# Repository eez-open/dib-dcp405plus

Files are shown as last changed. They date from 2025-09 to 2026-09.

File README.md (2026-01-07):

### This is a WORK IN PROGRESS!

---

### Ownership and License
The contributors are listed in CONTRIB.TXT. 

Licenses | OSHWA UID
--|--
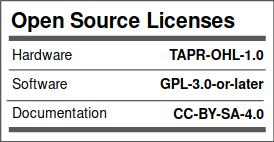
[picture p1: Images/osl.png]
osl
 | OSHW-HR000120 (https://certification.oshwa.org/hr000120.html)

### Overview

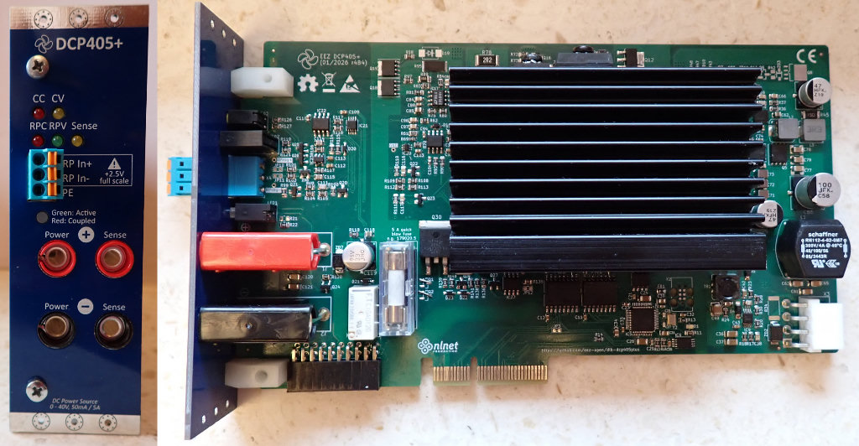
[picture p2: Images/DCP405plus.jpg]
3D model


The EEZ DIB DCP405+ Power module is an improved version of the [DCP405](https://github.com/eez-open/modular-psu/tree/master/dcp405) module that now includes an on-board 32-bit MCU, a more accurate and faster A/D converter for simultaneous voltage and current measurement (and thus more accurate power measurement).
This version features remote current programming in addition to the existing remote voltage programming. Sense inputs are also on 4 mm safety sockets, which now enables usage of widely available (e.g. AliExpress, eBay, etc.) and affordable Kelvin cable sets (Power/Sense) usually used with LCR meters (see below)

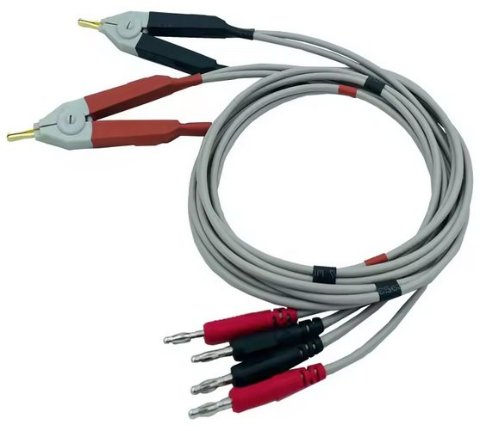
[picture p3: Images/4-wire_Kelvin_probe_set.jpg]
Probe set


### Feature list
- Power input: 48 Vdc (e.g. Mean Well EPP-150-48 or LRS-150F-48)
- Max. output power: 155 W (as limited with Mean Well AC/DC module capacity) 
- Voltage regulation (CV), 0 – 40 V. Voltage set resolution (_U_SET_): 16-bit, read resolution (_U_MON_): 15-bit
- Current regulation (CC) with 2-range (50 mA, 5 A). Current set resolution (_I_SET_): 16-bit, Current read resolution (_I_MON_): 20-bit for each range
- On-board low EMI switching power pre-regulator and bias power supply
- On-board OVP with full range dual crowbar (triac/MOSFET) and 20x5 mm fuse
- Down-programmer
- Output enable (OE) circuit with LED indicator combined with coupling indication
- Ø4 mm sockets (19.05 mm/0.75” pitch) for Power outputs and Sense inputs 
- Pass-thru connector for power output coupling with other power boards for e.g. doubling output voltage (up to 80 V) or current (up to 10 A)
- Remote voltage sense with LED indicator and inverse polarity protection
- Remote voltage and current programming with LED indicator (+2.5 V for full range)
- On-board 32-bit 250 MHz MCU ([STM32H503CBT6](https://www.st.com/en/microcontrollers-microprocessors/stm32h503cb.html))
- Galvanically isolated SPI bus
- I2C EEPROM for storing board specific configuration and calibration parameters
- SPI Temperature sensor
- Dimensions: 180 x 103.5 mm, 4-layer PCB
- **CE certified design**

---

This work is financed by [NLnet](https://nlnet.nl/project/BB3-CM5/) foundation

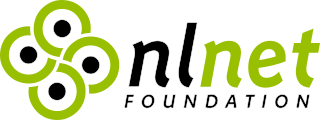
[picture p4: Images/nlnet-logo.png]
nlnet


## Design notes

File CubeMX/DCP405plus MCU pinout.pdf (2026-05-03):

DCP405plus MCU pinout | 03.05.2026
Pin Nb | PINs | FUNCTIONs | LABELs | NOTE
2 | PC13 | GPIO_Output | ACT_LED
4 | PC15-OSC32_OUT(OSC32_OUTGPIO_Input | TYPE_ID
5 | PH0-OSC_IN(PH0) | RCC_OSC_IN
6 | PH1-OSC_OUT(PH1) | RCC_OSC_OUT
10 | PA0 | SPI1_MISO | DIB_MISO
11 | PA1 | SPI1_NSS | DIB_CSA
12 | PA2 | SPI1_SCK | DIB_CLK
13 | PA3 | SPI3_MOSI | MOSI1
14 | PA4 | SPI1_MOSI | DIB_MOSI
15 | PA5 | SPI2_SCK | ADC_SCLK
16 | PA6 | GPIO_EXTI6 | IOEXP_IRQ
17 | PA7 | SPI2_MISO | ADC_MISO
18 | PB0 | GPIO_Output | DIB_IRQ
19 | PB1 | SPI2_MOSI | ADC_MOSI
20 | PB2 | GPIO_Input | ADC_IRQ
21 | PB10 | I2C1_SDA | DIB_SDA
25 | PB12 | GPIO_Output | IOEXP_CS
26 | PB13 | I2C1_SMBA | DIB_ALERT
27 | PB14 | USART1_TX
28 | PB15 | SPI3_MISO | MISO1
29 | PA8 | GPIO_Output | ADC_CS
30 | PA9 | GPIO_Output | DAC_CS
31 | PA10 | GPIO_Output | DIB_FAULT
32 | PA11 | USB_DM
33 | PA12 | USB_DP
34 | PA13(JTMS/SWDIO) | DEBUG_JTMS-SWDIO | JTAG_DIO
37 | PA14(JTCK/SWCLK) | DEBUG_JTCK-SWCLK | JTAG_CLK
38 | PA15(JTDI) | SPI3_SCK | SCLK1
39 | PB3(JTDO/TRACESWO) | DEBUG_JTDO-SWO | JTAG_SWO
40 | PB4(NJTRST) | TIM1_CH2 | AC_FREQ

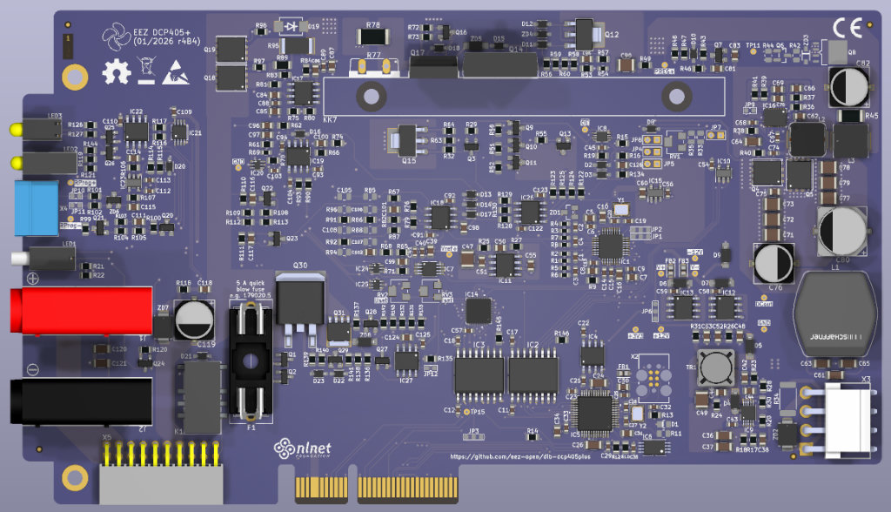
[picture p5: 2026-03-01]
Images/DCP405plus_3D.jpg

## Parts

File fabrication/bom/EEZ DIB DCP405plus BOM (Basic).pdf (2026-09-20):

EEZ DIB DCP405plus BOM (Basic), 20.09.2026

# | Reference | Value | Qty | DigiKey | Mouser | TME | LCSC

1 | C1,C2,C3,C4,C32,C59 | 1n | 6 | 732-7858-1-ND | 81-GRT1885C2A102JA2D C0805C102J5GAC
2 | | 1u | 14 | 587-1283-1-ND | | CL21B105KOFNNNE
3 | | 100n | 36 | 490-4774-1-ND | 80-C0603C104M4R | CL10B104KA8NNNC
4 | C14 | 270n | 1 | 490-16405-1-ND | GCM188R71C274KA37D C710684
5 | C17,C18 | 10p | 2 | 1276-1069-1-ND | 187-CL10C100CB8NNNC VJ0603A100JXACW1BC C318677
6 | C24,C26 | 2u2 | 2 | 490-12332-1-ND | | GRT188R61H225KE13D
7 | C27,C28 | 30p | 2 | 1292-1515-1-ND | 80-C0603C300G5HACTU 0603N300J500CT | C123555
8 | C34,C44,C119,C121,C122 | 4u7 | 5 | 1276-1244-1-ND | 187-CL21A475KAQNNNE CL21A475KAQNNNE | C1779
9 | C40,C120 | 22u | 2 | 1276-1101-1-ND | 187-CL32A226KAJNNNE CL32A226KAJNNNE | C52306
10 | C46,C48,C50,C105,C106 | 10n/200V | 5 | 311-4491-1-ND | 603-C1206KRX7RABB103 VJ1206Y103KXCTW1BC
11 | C47,C60,C103 | 470n/100V | 3 | 587-5014-1-ND | GRM21BR72A474KA73L C97926
12 | C49,C112,C113 | 2u2 | 3 | 1276-3138-1-ND | 187-CL31B225KCHSNNE C3216X7S2A225KAB
13 | C51,C54,C69,C71,C80,C114,C115 | 10n | 7 | 490-7194-1-ND | 710-885012207122 | CC0805KRX7R9103
14 | C53 | 15p | 1 | 399-C0603C150J5GAC7867TR-ND 80-C0603C150J5G | C0603C150J5GAC
15 | C55,C87 | 150p | 2 | 1276-1828-1-ND | 80-C0805C151J5G | CC0805JRNPO9BN151
16 | C56,C57,C58,C75 | 4u7/100V | 4 | 587-5034-1-ND | 810-CGA6M3X7S2A475K -
17 | C61,C67 | EEEFK1H470P | 2 | PCE3815CT-ND | 667-EEE-FK1H470P | EEEFK1H470P | C278400
18 | C62,C63,C64 | 10u | 3 | 1276-6736-1-ND | 187-CL32A106KBJNNNE CL31A106KBHNNNE
19 | C65 | EEEFK1J101P | 1 | PCE3819CT-ND | 667-EEE-FK1J101P | EEEFK1J101P | C128460
20 | C66 | 470p | 1 | 732-7837-1-ND | 710-885012007038 | CC0805JRNPO9BN471
21 | C81 | 6n8 | 1 | 1276-1799-1-ND | 80-C0805C682K5R | CL21B682KBANNNC
22 | C82,C109,C111 | 4n7 | 3 | 732-12255-1-ND | 810-C2012C0G1H472J-1 GRM2165C1H472JA01D
23 | C83 | 100p | 1 | 399-15000-1-ND | 80-C0805C101K5G | CL21C101JBANNNC
24 | C84,C85 | 2n2 | 2 | 399-C0805C222K5RAC7210TR-ND 80-C0805C222K5RACLR CL21B222JBANNNC | C307541
25 | C86,C118 | 330p | 2 | 1276-1189-1-ND | 80-C0805C331J5G | CL21C331JBANNNC
26 | C104 | 33u/50V poly. | 1 | | | - | C2157841
27 | C117 | 33p | 1 | 1276-1105-1-ND | C0805C330K5GACTU | CL21C330JBANNNC
28 | | BAS316 | 15 | 1727-7370-1-ND | 771-BAS316-T/R | BAS316,115 | C109218
29 | D5,D20,D21,D22,D23 | SKL16 | 5 | RB160MM-60CT-ND | 755-RB160MM-60TR | SKL16-DIO | -
30 | F1 | ZH32 | 1 | 732-11370-ND | 710-696101000002 | ZH32
31 | FB1,FB2,FB3 | BLM18AG102SH1D | 3 | 490-7809-1-ND | 81-BLM18AG102SH1D | BLM18AG102SH1D | C337877
32 | IC1 | ADS131A04IPBSR | 1 | 296-44202-1-ND | 595-ADS131A04IPBSR | - | C882747
33 | IC2,IC3 | ISO6762FDWR | 2 | 296-ISO6762FDWRCT-ND | 595-ISO6762FDWR | - | C5216396

C5,C7,C8,C10,C16,C30,C31,C36,C41,C 42,C68,C70,C72,C126

603-
CC805MKX7R7BB105
C6,C9,C11,C12,C13,C15,C19,C20,C21, C22,C23,C25,C29,C33,C35,C37,C38,C3 9,C43,C45,C52,C73,C74,C76,C77,C78, C79,C88,C89,C107,C108,C110,C116,C1 23,C124,C125
81-
GCM188R71C274KA7D

81-
GRT188R61H225KE3D

963-
HMK212C7474MGHTE

565-HHXD630ARA330MHA0GCT-ND

661-
XD630ARA330MHA0G

D1,D2,D3,D4,D6,D7,D8,D9,D10,D11,D1 2,D13,D14,D18,D19

34 | IC4 | ISO6520DR | 1 | 296-ISO6520DRCT-ND | 595-ISO6520DR | - | C32273056
35 | IC5 | STM32H503CBT6 | 1 | 497-STM32H503CBT6-ND | 511-STM32H503CBT6 | STM32H503CBT6 | C17700273
36 | IC6 | M24C32-DFDW6TP | 1 | 497-16067-1-ND | 511-M24C32-DFDW6TP M24C32-DFDW6TP | C2971426
37 | IC7 | DAC8552IDGKR | 1 | 296-46082-1-ND | 595-DAC8552IDGKR | - | C136020
38 | IC8 | 74AUP1G74DC,125 | 1 | 1727-6029-2-ND | 771-AUP1GDC125 | 74AUP1G74DC.125 | C458192
39 | IC9 | TMP126NDCKR | 1 | 296-TMP126NDCKRCT-ND | 595-TMP126NDCKR | TMP126NDCKR | C5219998
40 | IC10 | REF5025AIDR | 1 | 296-39165-1-ND | 595-REF5025AIDR | - | C11341
41 | IC11 | PCAL9722HNMP | 1 | 568-PCAL9722HNMPTR-ND | 771-PCAL9722HNMP | - | C24212503
42 | IC12 | LM5145RGYR | 1 | 296-47661-1-ND | 595-LM5145RGYR | - | C485912
43 | IC13 | LTC2050HVCS8#PBF | 1 | LTC2050HVCS8#PBF-ND | 584-LTC2050HVCS8#PBF - | C679141
44 | IC14,IC15 | TL072D | 2 | 296-1282-1-ND | 595-TL072CDR | TL072CD-ST | C67473
45 | IC16 | SN74LVC1G3157DCKR | 1 | 296-14909-1-ND | SN74LVC1G3157DCKR C38663
46 | IC22 | LM293D | 1 | LM293DR2GOSCT-ND | 863-LM293DR2G | LM293DR | C76509
47 | IC23 | MAX9141ESA | 1 | MAX9141ESA+-ND | 700-MAX9141ESA | - | C3658498
48 | IC24 | TPS54060DGQ | 1 | 296-37148-1-ND | TPS54060ADGQR | - | C12382
49 | IC25 | MC79L05 | 1 | MC79L05ABDGOS-ND | 863-MC79L05ACDR2G | MC79L05ACDG | C232661
50 | IC26 | MC78L05 | 1 | MC78L05ACDR2GOSCT-ND | 863-MC78L05ACDR2G | MC78L05ACDG | C7371
51 | IC27 | TPS7A2033PDBVR | 1 | 296-TPS7A2033PDBVRCT-ND | 595-TPS7A2033PDBVR | TPS7A2033PDBVR | C2862740
52 | J1 | 571-0500 | 1 | - | 164-6219 | 571-0500 | -
53 | J2 | 571-0100 | 1 | - | 164-6218 | 571-0100 | -
54 | KK1,KK2,KK3,KK4,KK7 | M3X8/D7985B | 5 | - | - | M3X8/D7985B
55 | KK5 | SK96/84SA | 1 | 5496-SK9684SA-ND | - | SK96/84SA | -
56 | KK6 | SP400-0.007-00-104 | 1 | BER204-ND | 951-SP400-007-00-104
57 | KK8 | B3/BN2842 | 1 | - | - | B3/BN2842
58 | KK9,KK10 | PCB-MB-01 | 2 | RPC1760-ND | 144-PCB-MB-01 | RI-PCB-MB-01 | C959626
59 | L1 | RN112-4-02-0M7 | 1 | 817-2100-ND | 631-RN112-4-02-0M7 | -
60 | L2 | ETQ-P4M100KFM | 1 | P124167CT-ND | 667-ETQ-P4M100KFM | -
61 | L3 | HPI0630-3R3 | 1 | 445-180834-1-ND | 810-VLS6045AF-3R3N | HPI0630-3R3
62 | LED2 | WP42WUM/EGW | 1 | 754-1718-ND | 604-WP42WUM/EGW | L-42WUM/1EGWT
63 | LED4 | WP934MD/LYLID | 1 | 350-2716-ND | 604-WP934MDLYLID | - | -
64 | Q1 | BSS84 | 1 | BSS84LT1GOSCT-ND | 863-BSS84LT1G | BSS84LT1G | C82079
65 | Q2 | BSC117N08NS5ATMA1 | 1 | BSC117N08NS5ATMA1CT-ND | BSC117N08NS5ATMA1 C3278730
66 | Q3 | BSC039N06NSATMA1 | 1 | BSC039N06NSATMA1CT-ND | | BSC039N06NS | C6471340
67 | Q5,Q8,Q9 | MMBT5401 | 3 | MMBT5401-FDICT-ND | 621-MMBT5401-F | MMBT5401-DIO | C21488
68 | Q7,Q11,Q26 | MMBT5551 | 3 | MMBT5551LT1GOSCT-ND | 637-MMBT5551 | MMBT5551-DIO | C41095
69 | Q10,Q13 | BCP56-16.115 | 2 | BCP5616QTADICT-ND | 621-BCP5616QTA | BCP56-16T1G
70 | Q12 | IRFP250NPBF | 1 | IRFP250NPBF-ND | 942-IRFP250NPBF | IRFP250NPBF
71 | Q14 | BC857C | 1 | 4878-BC857CCT-ND | 637-BC857C | BC857C-DIO | C8666
72 | Q15 | IRFI9Z34GPBF | 1 | IRFI9Z34GPBF-ND | 844-IRFI9Z34GPBF | IRFI9Z34GPBF | C222460
73 | Q16,Q17 | PSMN0R9-25YLC | 2 | 1727-5292-1-ND | 771-PSMN0R925YLC115 PSMN0R9-25YLC.115 | C179450
74 | Q23,Q24,Q25 | 2N7002 | 3 | T2N7002AKLMCT-ND | 757-T2N7002AKLM | 2N7002LT1G
75 | Q27 | FMMT493TA | 1 | FMMT493CT-ND | 522-FMMT493TA | FMMT493TA

595-
SN74LVC1G3157DCK

726-
BSC117N08NS5ATMA
726-
BSC039N06NSATMA1

76 | Q28 | BT139B-600E | 1 | 1740-1053-1-ND | 771-BT139B-600E118 | BT139B-600E.118 | C6533556
77 | Q29 | PSMN013-60YL | 1 | 1727-2589-1-ND | 771-PSMN013-60YLX | PSMN013-60YLX | C503662
78 | R1,R2,R3,R4,R5,R6,R7,R8,R47 | 100R | 9 | 13-RC0603FR-10100RLCT-ND | 603-RT0603FRE07100RL RC0603FR-10100RL | C1512171
79 | R9,R21,R33,R42,R147,R148,R151 | 10R | 7 | YAG1320CT-ND | 603-RC0805FR-0710RP SMD0805-10R-1% | C859127
80 | | 10K | 22 | 311-10.0KCRCT-ND | 603-RC0805FR-0710KL | RC0805FR-1310KL
81 | R11,R13,R19 | 1K8 | 3 | 311-1.80KCRCT-ND | 603-RC0805FR-131K8L | SMD0805-1K8-1% | C137579
82 | R15,R108,R109,R110,R111 | 0R | 5
83 | R17,R23,R39,R136 | 100K | 4 | RMCF0805FT100KCT-ND | | 0805S8F1003T5E
84 | R20,R129 | 330R | 2 | A129743CT-ND | 652-CR0805FX-3300ELF 0805S8F3300T5E
85 | R22,R115 | 1R | 2 | 13-RC0805FR-131RLCT-ND | 603-RC0805FR-131RL | RC0805FR-131RL | C7336808
86 | R30,R50,R63,R90,R91,R144 | 47K | 6 | RHM47KKCT-ND | 603-RC0805FR-0747KL | RC0805FR-0747K
87 | R31,R48,R54 | 470R | 3 | 311-470CRCT-ND | 71-CRCW0805470RFKEB RC0805FR-07470R
88 | R34,R120,R121 | 3K9 | 3 | A126369CT-ND | 279-CRGP0805F3K9 | SMD0805-3K9-1%
89 | R38 | 15R | 1 | A129910CT-ND | 603-RC2010FK-0715RL | 201007J0150T4E
90 | | 1K | 9 | RC0805FR-071KL | 603-RC0805FR-071KL | RC0805FR-071K
91 | R43 | 1K2 | 1 | 311-1.20KCRCT-ND | 603-RC0805FR-071K2L | SMD0805-1K2-1% | C114526
92 | R44,R45,R57,R86 | 220R | 4 | RMCF0805FT220RCT-ND | 603-RC0805FR-13220RL 0805S8F2200T5E
93 | R46,R149 | 51K | 2 | 311-51.0KCRCT-ND | 603-RC0805FR-0751KL | SMD0805-51K-1% | C107233
94 | R51,R59,R64,R65,R66,R67,R143 | 2K2 | 7 | 311-2.20KCRCT-ND | 603-RC0805FR-072K2L | 0805S8F2201T5E
95 | R52 | 16K | 1 | 311-16.0KCRCT-ND | 603-RC0805FR-0716KL | SMD0805-16K-1% | C137588
96 | R53,R124,R125 | 750R | 3 | A126385CT-ND | | 0805S8F7500T5E | C17818
97 | R61 | 6K8 | 1 | 311-6.80KCRCT-ND | 603-RC0805FR-076K8L | SMD0805-6K8-1% | C114550
98 | R62 | 3K | 1 | 311-3.00KCRCT-ND | 603-RC0805FR-073KL | SMD0805-3K-1% | C126350
99 | R68,R122,R123 | 6K2 | 3 | 311-6.20KCRCT-ND | 603-RC0805FR-076K2L | - | C114535
100 | R71 | 2R2/2-3W | 1 | CRM2512-JW-2R2ELFCT-ND | 279-35222R2JT | WF25P2R2JTL
101 | R72,R75 | 7K5 0.1% | 2 | YAG1974CT-ND | 279-CPF0805B7K5E1 | AR05BTCW7501
102 | R73,R74 | 36K 0.1% | 2 | YAG4886CT-ND | 603-RT0805BRD0736K5L - | C865431
103 | R76,R77 | 750R 0.1% | 2 | YAG4940CT-ND | 603-RT0805BRD07750RL ERA6AEB751V | C728656
104 | R79,R80 | 100K 0.1% | 2 | YAG4808CT-ND | 603-RT0805BRB07100KL RT0805BRD07100KL | C122537
105 | R82 | 1R 0.1% | 1 | 1712-CPF1206B1R0E1CT-ND | 279-CPF1206B1R0E1 | - | C4106088
106 | R84,R85 | 24K 0.1% | 2 | P24KBFCT-ND | 667-ERA-6ARB243V | - | C136924
107 | R88 | 0R010 | 1 | 846-GMR100HJBFA10L0CT-ND | GMR100HJBFA10L0 | - | -
108 | R132,R150 | 4K7 | 2 | 311-4.70KCRCT-ND | 603-RC0805FR-074K7L | 0805S8F4701T5E | C60816
109 | R139 | 6R2 | 1 | 311-6.20CRCT-ND | 603-RC0805FR-076R2L | RC0805JR-076R2
110 | R145 | 330K | 1 | A126361CT-ND | 652-CR0805FX-3303ELF 0805S8F3303T5E
111 | R146 | 86K6 | 1 | 311-86.6KCRCT-ND | 603-RT0805FRE0786K6L CRCW080586K6FKTABC
112 | TR1 | EPP-150-48 | 1 | 1866-1644-ND | 709-EPP150-48 | EPP-150-48 | C5729605
113 | TR2 | SRF0703-821M | 1 | SRF0703-821MCT-ND | 652-SRF0703-821M | -

R10,R14,R16,R18,R24,R25,R29,R32,R3 6,R40,R58,R69,R83,R126,R127,R128,R 130,R131,R133,R140,R141,R142

71-
CRCW0805100KFKEAC

R41,R49,R55,R56,R60,R134,R135,R137 ,R138

71-
CRCW0805750RFKEAC

114 | X3 | B4PS-VH (LF)(SN) | 1 | 455-B4PS-VH-ND | 306-B4PS-VHLFSN | B4PS-VH (LF)(SN)
115 | X5 | ZL263-20DG | 1 | PPPC102LJBN-RC | - | ZL263-20DG | C239361
116 | Y1 | 1 | 535-9676-1-ND | 520-CS163841033JGNTR - | C17254510
117 | Y2 | | 1 | 535-14398-1-ND | 815-ABM825MHZD2XT | - | C1986777
118 | ZD4 | BZX384-C15 | 1 | 1727-4986-1-ND | 78-BZX384C15-E3-08 | BZX384-C15.115 | C454989
119 | ZD5 | BZT52C6V2 | 1 | 4878-BZT52C6V2CT-ND | 621-BZT52C6V2-13-F | BZT52C6V2GW | C397931
120 | ZD7 | P6SMB68A | 1 | P6SMB68ABBCT-ND | 652-P6SMB68A | P6SMB68A-LF | C126829
121 | ZD8 | MMSZ5230BT1G | 1 | MMSZ5230BT1GOSCT-ND | 863-MMSZ5230BT1G | MMSZ5230BT1G
| | ECS-163.84-10-33-JGN- TR ABM8-25.000MHZ-D2X- T

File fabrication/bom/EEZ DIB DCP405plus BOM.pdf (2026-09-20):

EEZ DIB DCP405plus BOM, 20.09.2026

# | Reference | Value | Qty | DigiKey | Mouser | TME | LCSC

1 | C1,C2,C3,C4,C32,C59 | 1n | 6 | 732-7858-1-ND | 81-GRT1885C2A102JA2D C0805C102J5GAC
2 | | 1u | 14 | 587-1283-1-ND | | CL21B105KOFNNNE
3 | | 100n | 40 | 490-4774-1-ND | 80-C0603C104M4R | CL10B104KA8NNNC
4 | C14 | 270n | 1 | 490-16405-1-ND | GCM188R71C274KA37D C710684
5 | C17,C18 | 10p | 2 | 1276-1069-1-ND | 187-CL10C100CB8NNNC VJ0603A100JXACW1BC C318677
6 | C24,C26 | 2u2 | 2 | 490-12332-1-ND | | GRT188R61H225KE13D
7 | C27,C28 | 30p | 2 | 1292-1515-1-ND | 80-C0603C300G5HACTU 0603N300J500CT | C123555
8 | C34,C44,C119,C121,C122 | 4u7 | 5 | 1276-1244-1-ND | 187-CL21A475KAQNNNE CL21A475KAQNNNE | C1779
9 | C40,C120 | 22u | 2 | 1276-1101-1-ND | 187-CL32A226KAJNNNE CL32A226KAJNNNE | C52306
10 | C46,C48,C50,C105,C106 | 10n/200V | 5 | 311-4491-1-ND | 603-C1206KRX7RABB103 VJ1206Y103KXCTW1BC
11 | C47,C60,C103 | 470n/100V | 3 | 587-5014-1-ND | GRM21BR72A474KA73L C97926
12 | C49,C112,C113 | 2u2 | 3 | 1276-3138-1-ND | 187-CL31B225KCHSNNE C3216X7S2A225KAB
13 | | 10n | 9 | 490-7194-1-ND | 710-885012207122 | CC0805KRX7R9103
14 | C53 | 15p | 1 | 399-C0603C150J5GAC7867TR-ND 80-C0603C150J5G | C0603C150J5GAC
15 | C55,C87 | 150p | 2 | 1276-1828-1-ND | 80-C0805C151J5G | CC0805JRNPO9BN151
16 | C56,C57,C58,C75 | 4u7/100V | 4 | 587-5034-1-ND | 810-CGA6M3X7S2A475K -
17 | C61,C67 | EEEFK1H470P | 2 | PCE3815CT-ND | 667-EEE-FK1H470P | EEEFK1H470P | C278400
18 | C62,C63,C64 | 10u | 3 | 1276-6736-1-ND | 187-CL32A106KBJNNNE CL31A106KBHNNNE
19 | C65 | EEEFK1J101P | 1 | PCE3819CT-ND | 667-EEE-FK1J101P | EEEFK1J101P | C128460
20 | C66 | 470p | 1 | 732-7837-1-ND | 710-885012007038 | CC0805JRNPO9BN471
21 | C81 | 6n8 | 1 | 1276-1799-1-ND | 80-C0805C682K5R | CL21B682KBANNNC
22 | C82,C109,C111 | 4n7 | 3 | 732-12255-1-ND | 810-C2012C0G1H472J-1 GRM2165C1H472JA01D
23 | C83,C99,C100 | 100p | 3 | 399-15000-1-ND | 80-C0805C101K5G | CL21C101JBANNNC
24 | C84,C85,C96 | 2n2 | 3 | 399-C0805C222K5RAC7210TR-ND 80-C0805C222K5RACLR CL21B222JBANNNC | C307541
25 | C86,C118 | 330p | 2 | 1276-1189-1-ND | 80-C0805C331J5G | CL21C331JBANNNC
26 | C104 | 33u/50V poly. | 1 | | | - | C2157841
27 | C117 | 33p | 1 | 1276-1105-1-ND | C0805C330K5GACTU | CL21C330JBANNNC
28 | | BAS316 | 17 | 1727-7370-1-ND | 771-BAS316-T/R | BAS316,115 | C109218
29 | D5,D20,D21,D22,D23 | SKL16 | 5 | RB160MM-60CT-ND | 755-RB160MM-60TR | SKL16-DIO | -
30 | F1 | ZH32 | 1 | 732-11370-ND | 710-696101000002 | ZH32
31 | FB1,FB2,FB3 | BLM18AG102SH1D | 3 | 490-7809-1-ND | 81-BLM18AG102SH1D | BLM18AG102SH1D | C337877
32 | IC1 | ADS131A04IPBSR | 1 | 296-44202-1-ND | 595-ADS131A04IPBSR | - | C882747

C5,C7,C8,C10,C16,C30,C31,C36,C41,C 42,C68,C70,C72,C126

603-
CC805MKX7R7BB105
C6,C9,C11,C12,C13,C15,C19,C20,C21, C22,C23,C25,C29,C33,C35,C37,C38,C3 9,C43,C45,C52,C73,C74,C76,C77,C78, C79,C88,C89,C94,C95,C97,C98,C107,C 108,C110,C116,C123,C124,C125
81-
GCM188R71C274KA7D

81-
GRT188R61H225KE3D

963-
HMK212C7474MGHTE

C51,C54,C69,C71,C80,C101,C102,C114 ,C115

565-HHXD630ARA330MHA0GCT-ND

661-
XD630ARA330MHA0G

D1,D2,D3,D4,D6,D7,D8,D9,D10,D11,D1 2,D13,D14,D16,D17,D18,D19

33 | IC2,IC3 | ISO6762FDWR | 2 | 296-ISO6762FDWRCT-ND | 595-ISO6762FDWR | - | C5216396
34 | IC4 | ISO6520DR | 1 | 296-ISO6520DRCT-ND | 595-ISO6520DR | - | C32273056
35 | IC5 | STM32H503CBT6 | 1 | 497-STM32H503CBT6-ND | 511-STM32H503CBT6 | STM32H503CBT6 | C17700273
36 | IC6 | M24C32-DFDW6TP | 1 | 497-16067-1-ND | 511-M24C32-DFDW6TP M24C32-DFDW6TP | C2971426
37 | IC7 | DAC8552IDGKR | 1 | 296-46082-1-ND | 595-DAC8552IDGKR | - | C136020
38 | IC8 | 74AUP1G74DC,125 | 1 | 1727-6029-2-ND | 771-AUP1GDC125 | 74AUP1G74DC.125 | C458192
39 | IC9 | TMP126NDCKR | 1 | 296-TMP126NDCKRCT-ND | 595-TMP126NDCKR | TMP126NDCKR | C5219998
40 | IC10 | REF5025AIDR | 1 | 296-39165-1-ND | 595-REF5025AIDR | - | C11341
41 | IC11 | PCAL9722HNMP | 1 | 568-PCAL9722HNMPTR-ND | 771-PCAL9722HNMP | - | C24212503
42 | IC12 | LM5145RGYR | 1 | 296-47661-1-ND | 595-LM5145RGYR | - | C485912
43 | IC13 | LTC2050HVCS8#PBF | 1 | LTC2050HVCS8#PBF-ND | 584-LTC2050HVCS8#PBF - | C679141
44 | IC14,IC15 | TL072D | 2 | 296-1282-1-ND | 595-TL072CDR | TL072CD-ST | C67473
45 | IC16,IC20,IC21 | SN74LVC1G3157DCKR | 3 | 296-14909-1-ND | SN74LVC1G3157DCKR C38663
46 | IC17 | SN74LVC2G08DCTR | 1 | 296-13263-2-ND | 595-SN74LVC2G08DCTR SN74LVC2G08DCTR | C352973
47 | IC18,IC22 | LM293D | 2 | LM293DR2GOSCT-ND | 863-LM293DR2G | LM293DR | C76509
48 | IC19 | OPA376AIDBVR | 1 | 296-39130-2-ND | 595-OPA376AIDBVR | OPA376AIDBVR | C42134
49 | IC23 | MAX9141ESA | 1 | MAX9141ESA+-ND | 700-MAX9141ESA | - | C3658498
50 | IC24 | TPS54060DGQ | 1 | 296-37148-1-ND | TPS54060ADGQR | - | C12382
51 | IC25 | MC79L05 | 1 | MC79L05ABDGOS-ND | 863-MC79L05ACDR2G | MC79L05ACDG | C232661
52 | IC26 | MC78L05 | 1 | MC78L05ACDR2GOSCT-ND | 863-MC78L05ACDR2G | MC78L05ACDG | C7371
53 | IC27 | TPS7A2033PDBVR | 1 | 296-TPS7A2033PDBVRCT-ND | 595-TPS7A2033PDBVR | TPS7A2033PDBVR | C2862740
54 | J1 | 572-0500 | 1 | - | 164-6221 | 572-0500 | -
55 | J2 | 572-0100 | 1 | - | 164-6220 | 572-0100 | -
56 | K1 | | 1 | 399-10997-1-ND | 80-EE2-12NU-L | FTR-C1GA012G-B05 | C147864
57 | KK1,KK2,KK3,KK4,KK7 | M3X8/D7985B | 5 | - | - | M3X8/D7985B
58 | KK5 | SK96/84SA | 1 | 5496-SK9684SA-ND | - | SK96/84SA | -
59 | KK6 | SP400-0.007-00-104 | 1 | BER204-ND | 951-SP400-007-00-104
60 | KK8 | B3/BN2842 | 1 | - | - | B3/BN2842
61 | KK9,KK10 | PCB-MB-01 | 2 | RPC1760-ND | 144-PCB-MB-01 | RI-PCB-MB-01 | C959626
62 | L1 | RN112-4-02-0M7 | 1 | 817-2100-ND | 631-RN112-4-02-0M7 | -
63 | L2 | ETQ-P4M100KFM | 1 | P124167CT-ND | 667-ETQ-P4M100KFM | -
64 | L3 | HPI0630-3R3 | 1 | 445-180834-1-ND | 810-VLS6045AF-3R3N | HPI0630-3R3
65 | LED2 | WP42WUM/EGW | 1 | 754-1718-ND | 604-WP42WUM/EGW | L-42WUM/1EGWT
66 | LED3 | SSF-LXH340LYGID | 1 | SSF-LXH340LYGID-ND | 696-SSFLXH340LYGID | - | C17285042
67 | LED4 | WP934MD/LYLID | 1 | 350-2716-ND | 604-WP934MDLYLID | - | -
68 | Q1 | BSS84 | 1 | BSS84LT1GOSCT-ND | 863-BSS84LT1G | BSS84LT1G | C82079
69 | Q2 | BSC117N08NS5ATMA1 | 1 | BSC117N08NS5ATMA1CT-ND | BSC117N08NS5ATMA1 C3278730
70 | Q3 | BSC039N06NSATMA1 | 1 | BSC039N06NSATMA1CT-ND | | BSC039N06NS | C6471340
71 | Q5,Q8,Q9,Q21 | MMBT5401 | 4 | MMBT5401-FDICT-ND | 621-MMBT5401-F | MMBT5401-DIO | C21488
72 | Q7,Q11,Q18,Q19,Q20,Q26 | MMBT5551 | 6 | MMBT5551LT1GOSCT-ND | 637-MMBT5551 | MMBT5551-DIO | C41095
73 | Q10,Q13 | BCP56-16.115 | 2 | BCP5616QTADICT-ND | 621-BCP5616QTA | BCP56-16T1G

595-
SN74LVC1G3157DCK

FTR-C1GA012G-B05 or
EE2-12NU-L

726-
BSC117N08NS5ATMA
726-
BSC039N06NSATMA1

74 | Q12 | IRFP250NPBF | 1 | IRFP250NPBF-ND | 942-IRFP250NPBF | IRFP250NPBF
75 | Q14 | BC857C | 1 | 4878-BC857CCT-ND | 637-BC857C | BC857C-DIO | C8666
76 | Q15 | IRFI9Z34GPBF | 1 | IRFI9Z34GPBF-ND | 844-IRFI9Z34GPBF | IRFI9Z34GPBF | C222460
77 | Q16,Q17 | PSMN0R9-25YLC | 2 | 1727-5292-1-ND | 771-PSMN0R925YLC115 PSMN0R9-25YLC.115 | C179450
78 | Q22,Q23,Q24,Q25 | 2N7002 | 4 | T2N7002AKLMCT-ND | 757-T2N7002AKLM | 2N7002LT1G
79 | Q27 | FMMT493TA | 1 | FMMT493CT-ND | 522-FMMT493TA | FMMT493TA
80 | Q28 | BT139B-600E | 1 | 1740-1053-1-ND | 771-BT139B-600E118 | BT139B-600E.118 | C6533556
81 | Q29 | PSMN013-60YL | 1 | 1727-2589-1-ND | 771-PSMN013-60YLX | PSMN013-60YLX | C503662
82 | R1,R2,R3,R4,R5,R6,R7,R8,R47 | 100R | 9 | 13-RC0603FR-10100RLCT-ND | 603-RT0603FRE07100RL RC0603FR-10100RL | C1512171
83 | R9,R21,R33,R42,R147,R148,R151 | 10R | 7 | YAG1320CT-ND | 603-RC0805FR-0710RP SMD0805-10R-1% | C859127
84 | | 10K | 28 | 311-10.0KCRCT-ND | 603-RC0805FR-0710KL | RC0805FR-1310KL
85 | R11,R13,R19 | 1K8 | 3 | 311-1.80KCRCT-ND | 603-RC0805FR-131K8L | SMD0805-1K8-1% | C137579
86 | R17,R23,R39,R118,R136 | 100K | 5 | RMCF0805FT100KCT-ND | | 0805S8F1003T5E
87 | R20,R103,R104,R116,R129 | 330R | 5 | A129743CT-ND | 652-CR0805FX-3300ELF 0805S8F3300T5E
88 | R22,R115 | 1R | 2 | 13-RC0805FR-131RLCT-ND | 603-RC0805FR-131RL | RC0805FR-131RL | C7336808
89 | | 47K | 9 | RHM47KKCT-ND | 603-RC0805FR-0747KL | RC0805FR-0747K
90 | R31,R48,R54 | 470R | 3 | 311-470CRCT-ND | 71-CRCW0805470RFKEB RC0805FR-07470R
91 | R34,R120,R121 | 3K9 | 3 | A126369CT-ND | 279-CRGP0805F3K9 | SMD0805-3K9-1%
92 | R38 | 15R | 1 | A129910CT-ND | 603-RC2010FK-0715RL | 201007J0150T4E
93 | | 1K | 13 | RC0805FR-071KL | 603-RC0805FR-071KL | RC0805FR-071K
94 | R43 | 1K2 | 1 | 311-1.20KCRCT-ND | 603-RC0805FR-071K2L | SMD0805-1K2-1% | C114526
95 | R44,R45,R57,R86,R117 | 220R | 5 | RMCF0805FT220RCT-ND | 603-RC0805FR-13220RL 0805S8F2200T5E
96 | R46,R149 | 51K | 2 | 311-51.0KCRCT-ND | 603-RC0805FR-0751KL | SMD0805-51K-1% | C107233
97 | R51,R59,R64,R65,R66,R67,R106,R143 2K2 | 8 | 311-2.20KCRCT-ND | 603-RC0805FR-072K2L | 0805S8F2201T5E
98 | R52 | 16K | 1 | 311-16.0KCRCT-ND | 603-RC0805FR-0716KL | SMD0805-16K-1% | C137588
99 | R53,R102,R105,R124,R125 | 750R | 5 | A126385CT-ND | | 0805S8F7500T5E | C17818
100 | R61 | 6K8 | 1 | 311-6.80KCRCT-ND | 603-RC0805FR-076K8L | SMD0805-6K8-1% | C114550
101 | R62 | 3K | 1 | 311-3.00KCRCT-ND | 603-RC0805FR-073KL | SMD0805-3K-1% | C126350
102 | R68,R122,R123 | 6K2 | 3 | 311-6.20KCRCT-ND | 603-RC0805FR-076K2L | - | C114535
103 | R71 | 2R2/2-3W | 1 | CRM2512-JW-2R2ELFCT-ND | 279-35222R2JT | WF25P2R2JTL
104 | R72,R75 | 7K5 0.1% | 2 | YAG1974CT-ND | 279-CPF0805B7K5E1 | AR05BTCW7501
105 | R73,R74 | 36K 0.1% | 2 | YAG4886CT-ND | 603-RT0805BRD0736K5L - | C865431
106 | R76,R77 | 750R 0.1% | 2 | YAG4940CT-ND | 603-RT0805BRD07750RL ERA6AEB751V | C728656
107 | R79,R80 | 100K 0.1% | 2 | YAG4808CT-ND | 603-RT0805BRB07100KL RT0805BRD07100KL | C122537
108 | R82 | 1R 0.1% | 1 | 1712-CPF1206B1R0E1CT-ND | 279-CPF1206B1R0E1 | - | C4106088
109 | R84,R85 | 24K 0.1% | 2 | P24KBFCT-ND | 667-ERA-6ARB243V | - | C136924
110 | R88 | 0R010 | 1 | 846-GMR100HJBFA10L0CT-ND | GMR100HJBFA10L0 | - | -
111 | R113,R114,R132,R150 | 4K7 | 4 | 311-4.70KCRCT-ND | 603-RC0805FR-074K7L | 0805S8F4701T5E | C60816

R10,R14,R16,R18,R24,R25,R29,R32,R3 6,R40,R58,R69,R83,R92,R94,R95,R96, R99,R100,R126,R127,R128,R130,R131, R133,R140,R141,R142

71-
CRCW0805100KFKEAC

R30,R50,R63,R90,R91,R93,R97,R98,R1 44

R41,R49,R55,R56,R60,R101,R107,R112 ,R119,R134,R135,R137,R138

71-
CRCW0805750RFKEAC

112 | R139 | 6R2 | 1 | 311-6.20CRCT-ND | 603-RC0805FR-076R2L | RC0805JR-076R2
113 | R145 | 330K | 1 | A126361CT-ND | 652-CR0805FX-3303ELF 0805S8F3303T5E
114 | R146 | 86K6 | 1 | 311-86.6KCRCT-ND | 603-RT0805FRE0786K6L CRCW080586K6FKTABC
115 | TR1 | EPP-150-48 | 1 | 1866-1644-ND | 709-EPP150-48 | EPP-150-48 | C5729605
116 | TR2 | SRF0703-821M | 1 | SRF0703-821MCT-ND | 652-SRF0703-821M | -
117 | X3 | B4PS-VH (LF)(SN) | 1 | 455-B4PS-VH-ND | 306-B4PS-VHLFSN | B4PS-VH (LF)(SN)
118 | X4 | TBP03R1-350-03BE | 1 | 2223-TBP03R1-350-03BE-ND | 179-TBP03R1-350-03BE - | C3581987
119 | X5 | ZL263-20DG | 1 | PPPC102LJBN-RC | - | ZL263-20DG | C239361
120 | Y1 | 1 | 535-9676-1-ND | 520-CS163841033JGNTR - | C17254510
121 | Y2 | | 1 | 535-14398-1-ND | 815-ABM825MHZD2XT | - | C1986777
122 | ZD2,ZD7 | P6SMB68A | 2 | P6SMB68ABBCT-ND | 652-P6SMB68A | P6SMB68A-LF | C126829
123 | ZD4 | BZX384-C15 | 1 | 1727-4986-1-ND | 78-BZX384C15-E3-08 | BZX384-C15.115 | C454989
124 | ZD5 | BZT52C6V2 | 1 | 4878-BZT52C6V2CT-ND | 621-BZT52C6V2-13-F | BZT52C6V2GW | C397931
125 | ZD6 | SLVU2.8.TCT | 1 | CDSOT23-SLVU2.8TR-ND | 652-CDSOT23-SLVU2.8 SLVU2.8.TCT
126 | ZD8 | MMSZ5230BT1G | 1 | MMSZ5230BT1GOSCT-ND | 863-MMSZ5230BT1G | MMSZ5230BT1G

ECS-163.84-10-33-JGN-TR
ABM8-25.000MHZ-D2X-T

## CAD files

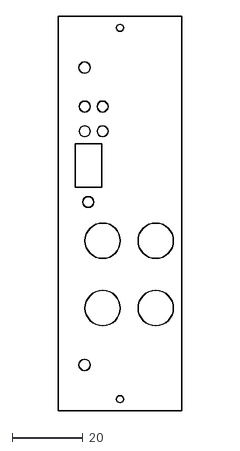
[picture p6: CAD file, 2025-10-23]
fabrication/dxf/EEZ DIB DCP405plus front mask-Edge_Cuts.dxf
35.0 x 111.5

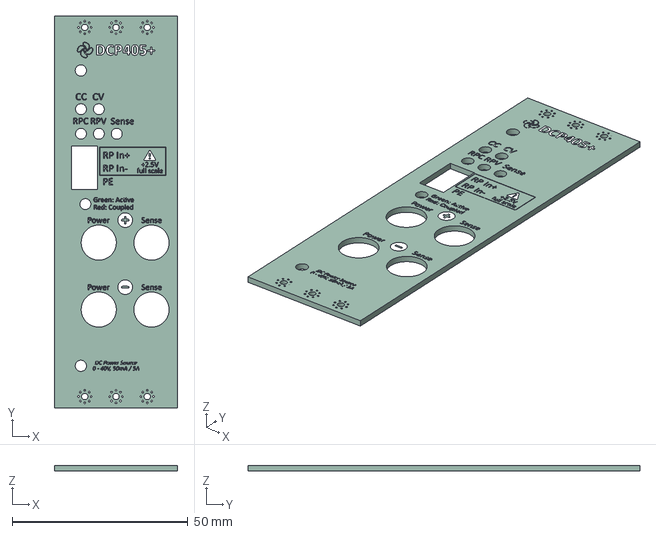
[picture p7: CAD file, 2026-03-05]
fabrication/step/EEZ DIB DCP405plus front mask.step
35.0 x 111.5 x 1.58 mm
EEZ DIB DCP405plus front mask_silkscreen
EEZ DIB DCP405plus front mask_PCB

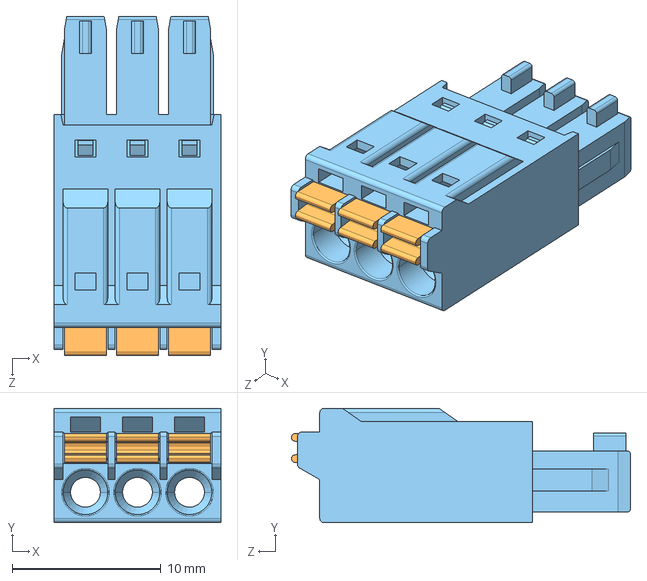
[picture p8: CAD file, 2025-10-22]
fabrication/step/Same_Sky_TBP03P2-350-03BEOR.step
11.2 x 7.70 x 22.8 mm

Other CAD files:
fabrication/dxf/EEZ DIB DCP405plus front mask.dxf

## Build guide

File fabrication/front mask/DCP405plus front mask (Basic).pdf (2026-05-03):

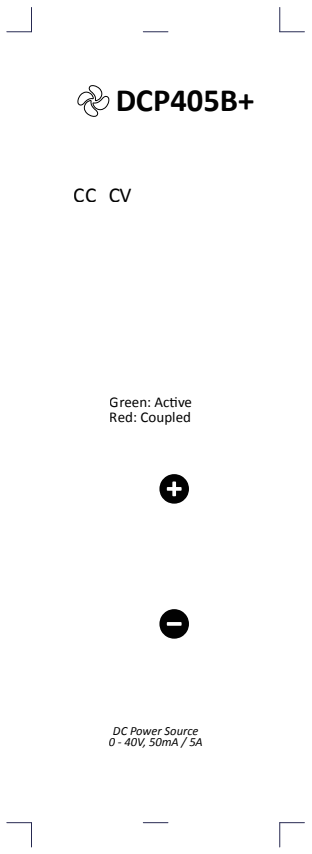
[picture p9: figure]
Green: Acve Red: Coupled; DC Power Source 0 - 40V, 50mA / 5A; DCP405B+

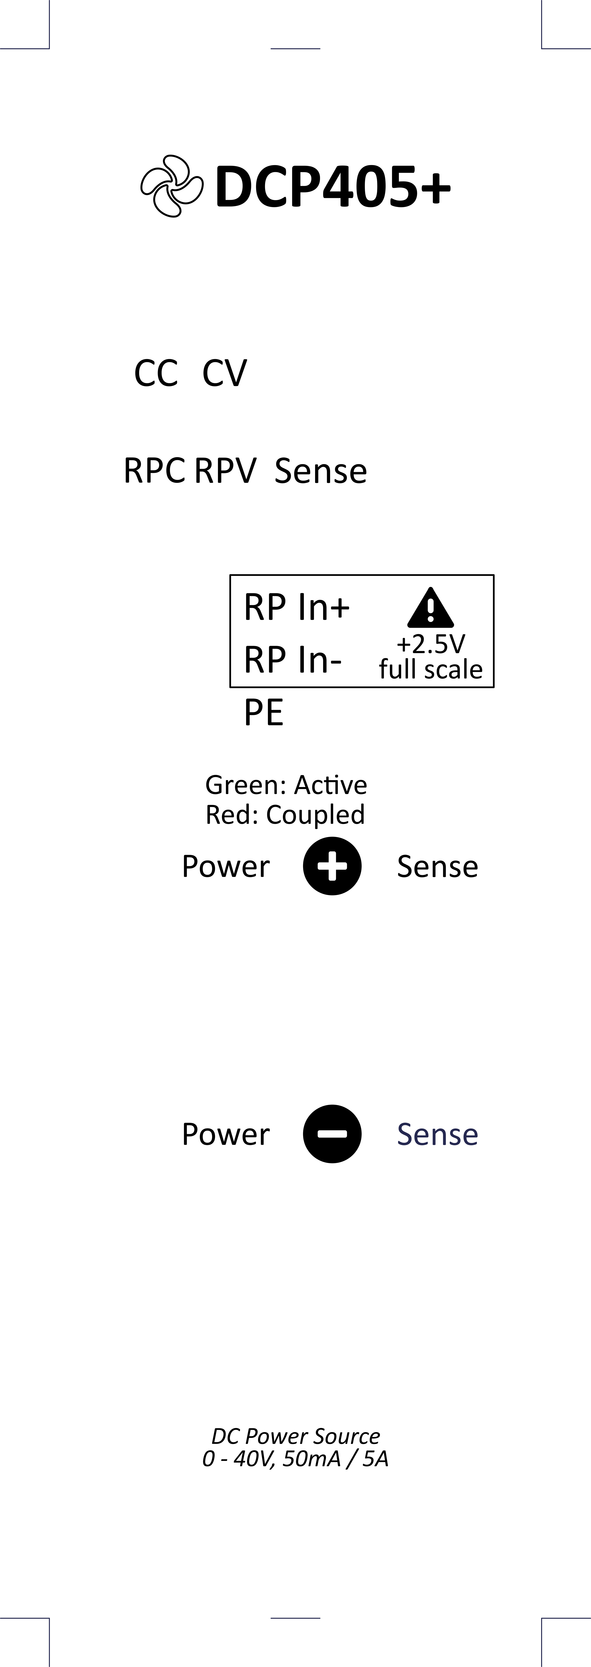
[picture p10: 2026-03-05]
fabrication/front mask/DCP405plus front mask.png

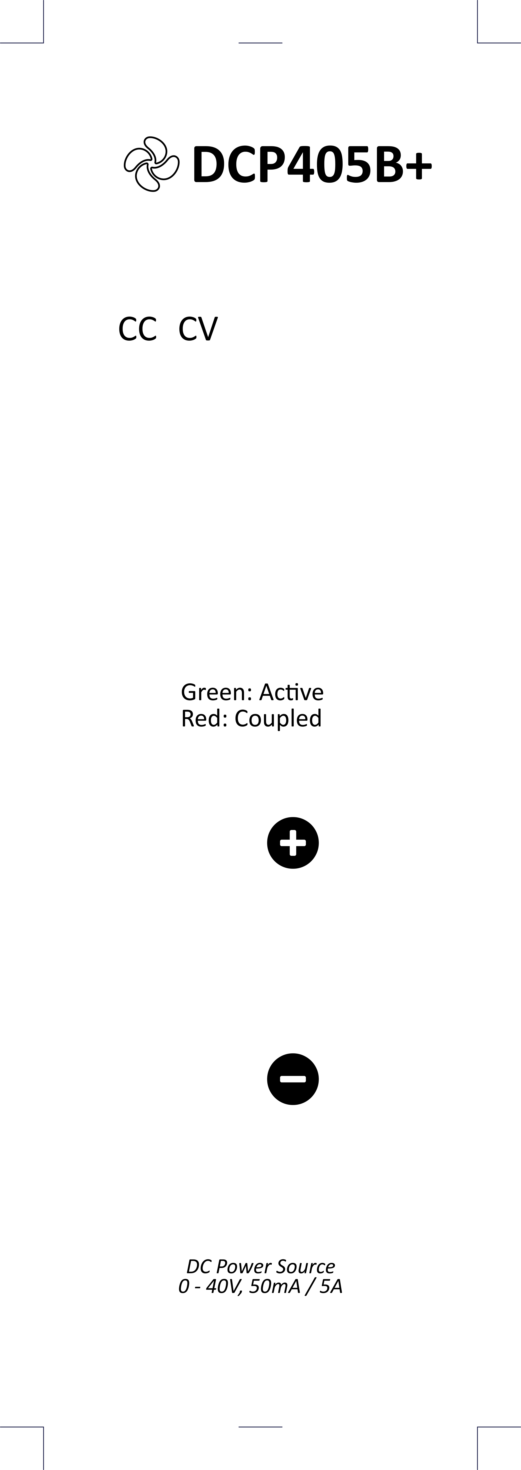
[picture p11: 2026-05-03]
fabrication/front mask/DCP405plus front mask (Basic).png

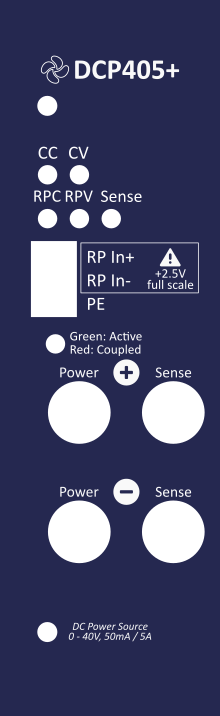
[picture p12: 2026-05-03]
fabrication/front mask/DCP405plus front mask (Simulator).png

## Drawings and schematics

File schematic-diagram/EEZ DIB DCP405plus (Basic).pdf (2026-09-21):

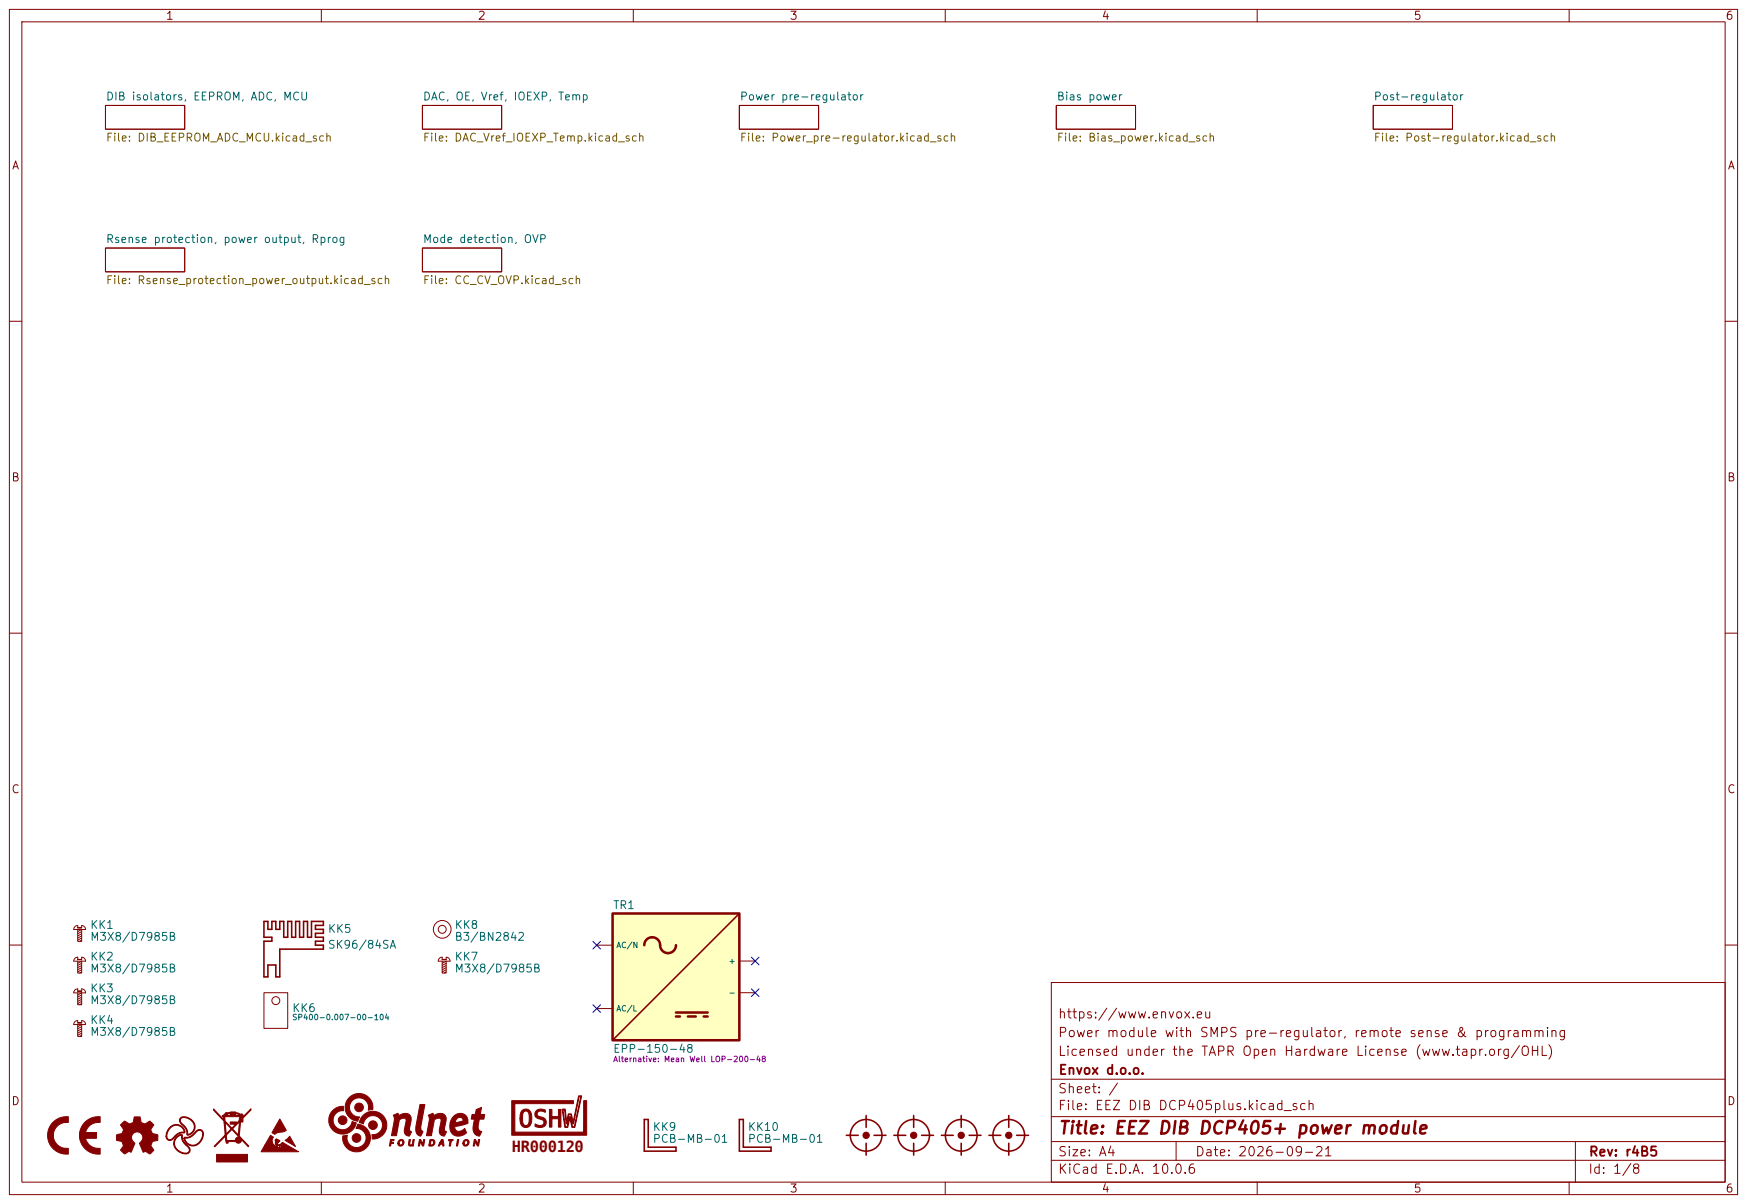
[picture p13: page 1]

File: Rsense_protection_power_output.kicad_sch DIB isolators, EEPROM, ADC, MCU

DAC, OE, Vref, IOEXP, Temp

Bias power File: Bias_power.kicad_sch Power pre-regulator File: Power_pre-regulator.kicad_sch

Post-regulator File: Post-regulator.kicad_sch

File: DAC_Vref_IOEXP_Temp.kicad_sch Rsense protection, power output, Rprog

https://www.envox.eu
Power module with SMPS pre-regulator, remote sense & programming
Licensed under the TAPR Open Hardware License (www.tapr.org/OHL)
Envox d.o.o.
Sheet: /
File: EEZ DIB DCP405plus.kicad_sch
Title: EEZ DIB DCP405+ power module

Alternative: Mean Well LOP-200-48 HR000120

Size: A4 | Rev: r4B5
KiCad E.D.A. 10.0.6 | Id: 1/8

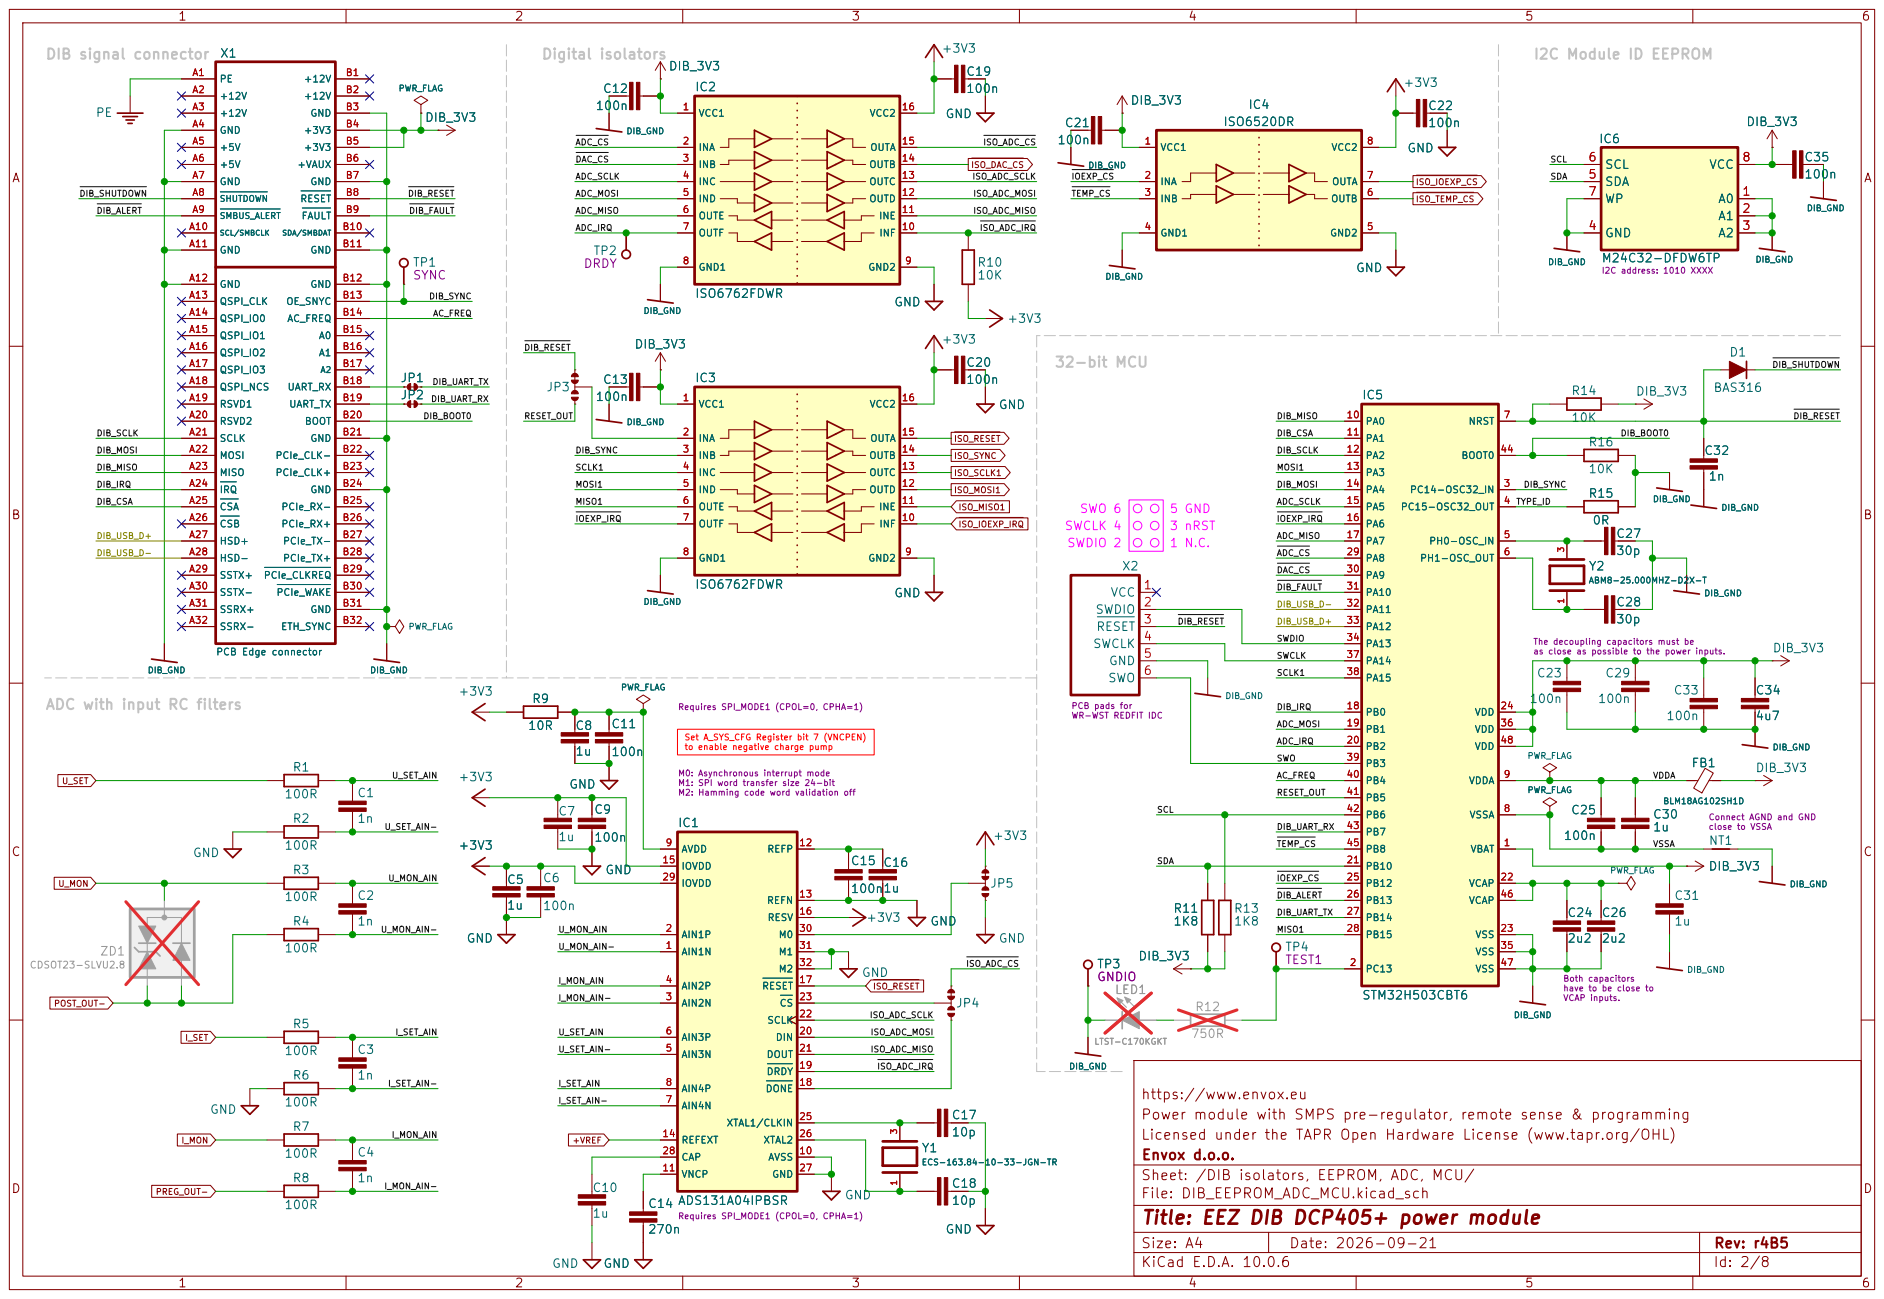
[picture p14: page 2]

to enable negative charge pump Digital isolators

ADC with input RC filters

PCB pads for WR-WST REDFIT IDC

Set A_SYS_CFG Register bit 7 (VNCPEN)

Connect AGND and GND
close to VSSA

ECS-163.84-10-33-JGN-TR JP4 GND
ISO_RESET

Both capacitors have to be close to

https://www.envox.eu
Power module with SMPS pre-regulator, remote sense & programming
Licensed under the TAPR Open Hardware License (www.tapr.org/OHL)
Envox d.o.o.
Sheet: /DIB isolators, EEPROM, ADC, MCU/
File: DIB_EEPROM_ADC_MCU.kicad_sch
Title: EEZ DIB DCP405+ power module

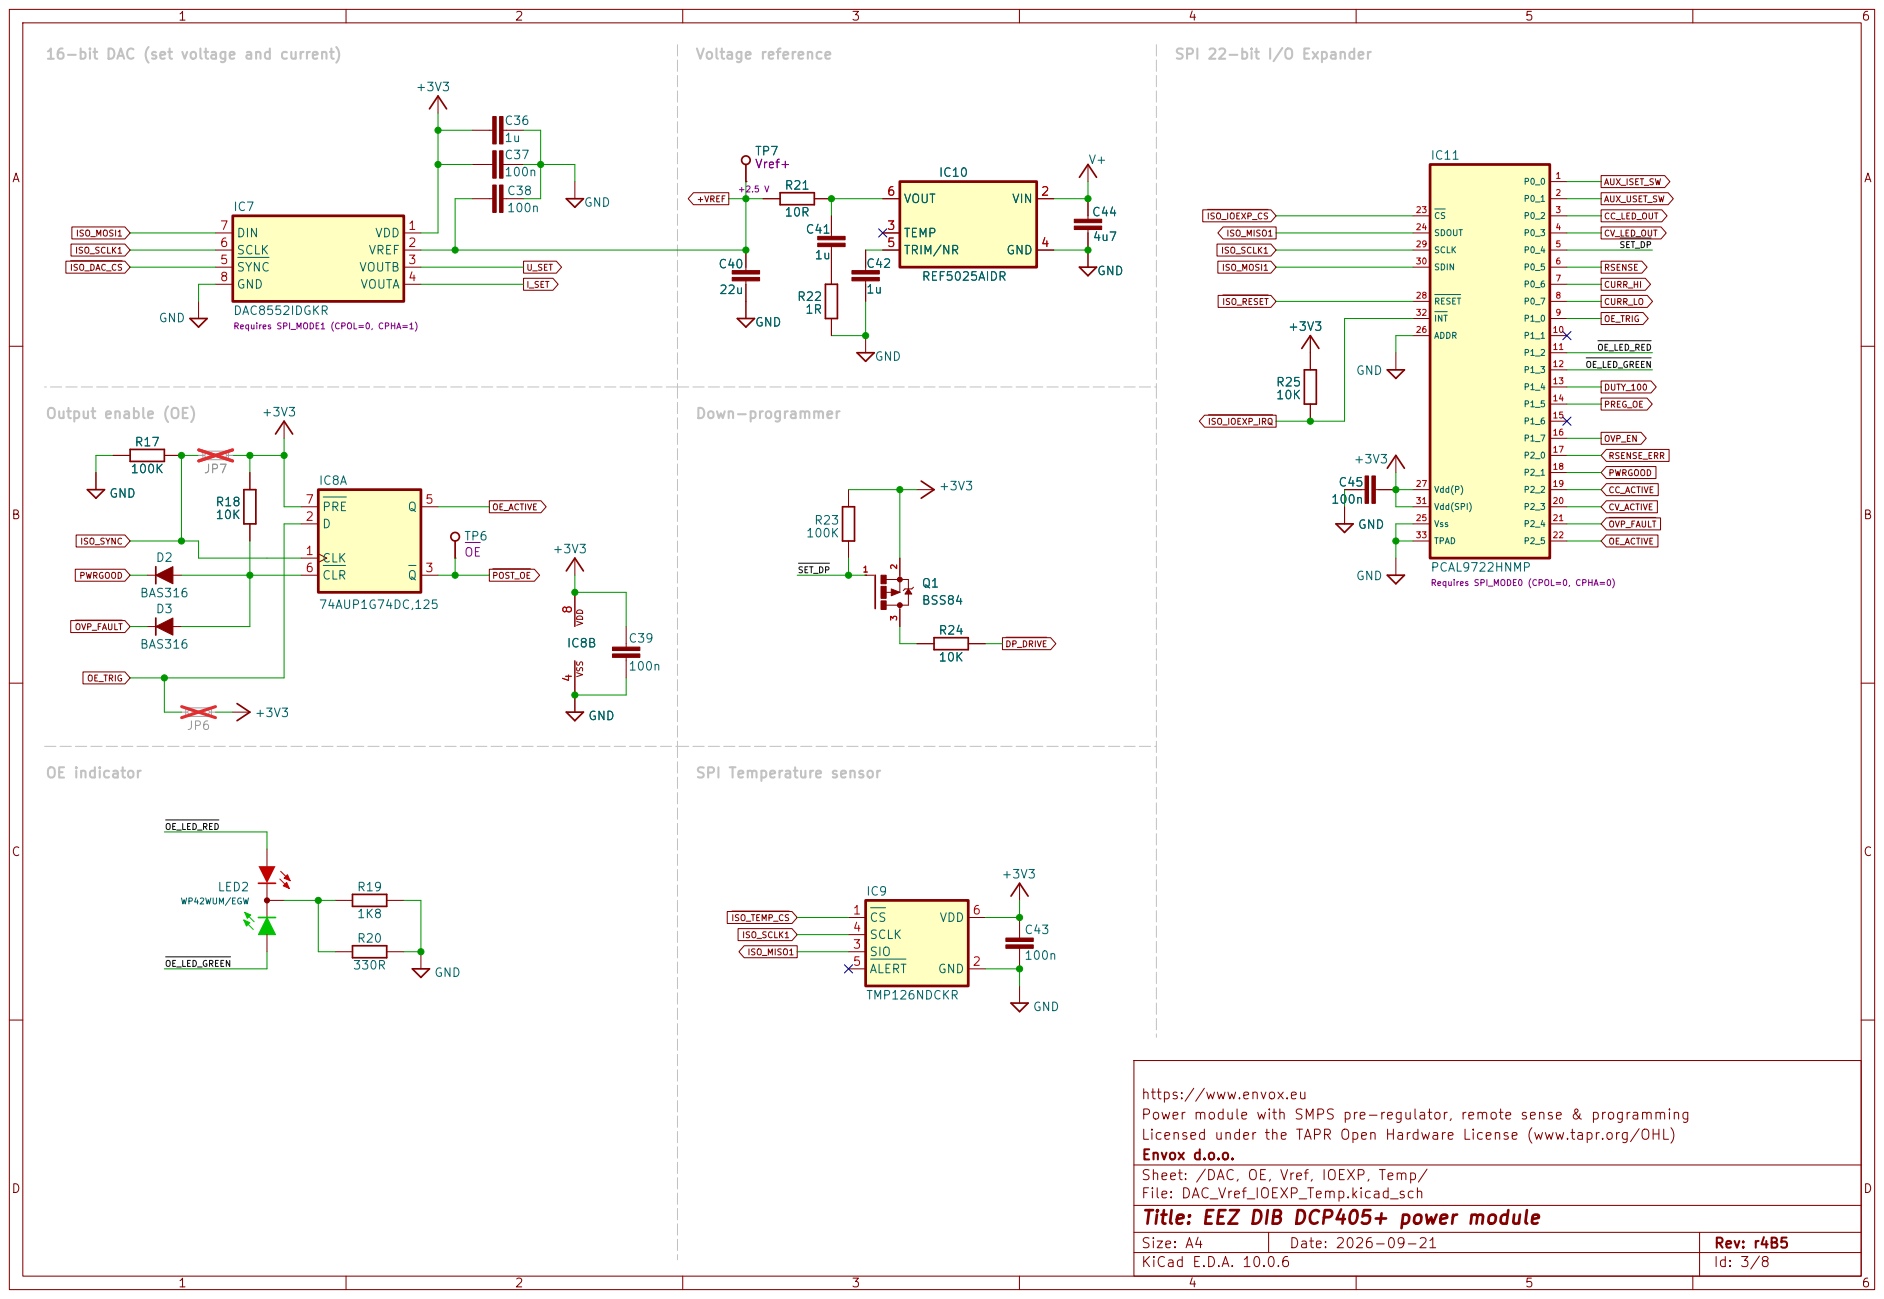
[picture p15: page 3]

Requires SPI_MODE1 (CPOL=0, CPHA=1) OE indicator

https://www.envox.eu
Power module with SMPS pre-regulator, remote sense & programming
Licensed under the TAPR Open Hardware License (www.tapr.org/OHL)
Envox d.o.o.
Sheet: /DAC, OE, Vref, IOEXP, Temp/
File: DAC_Vref_IOEXP_Temp.kicad_sch
Title: EEZ DIB DCP405+ power module

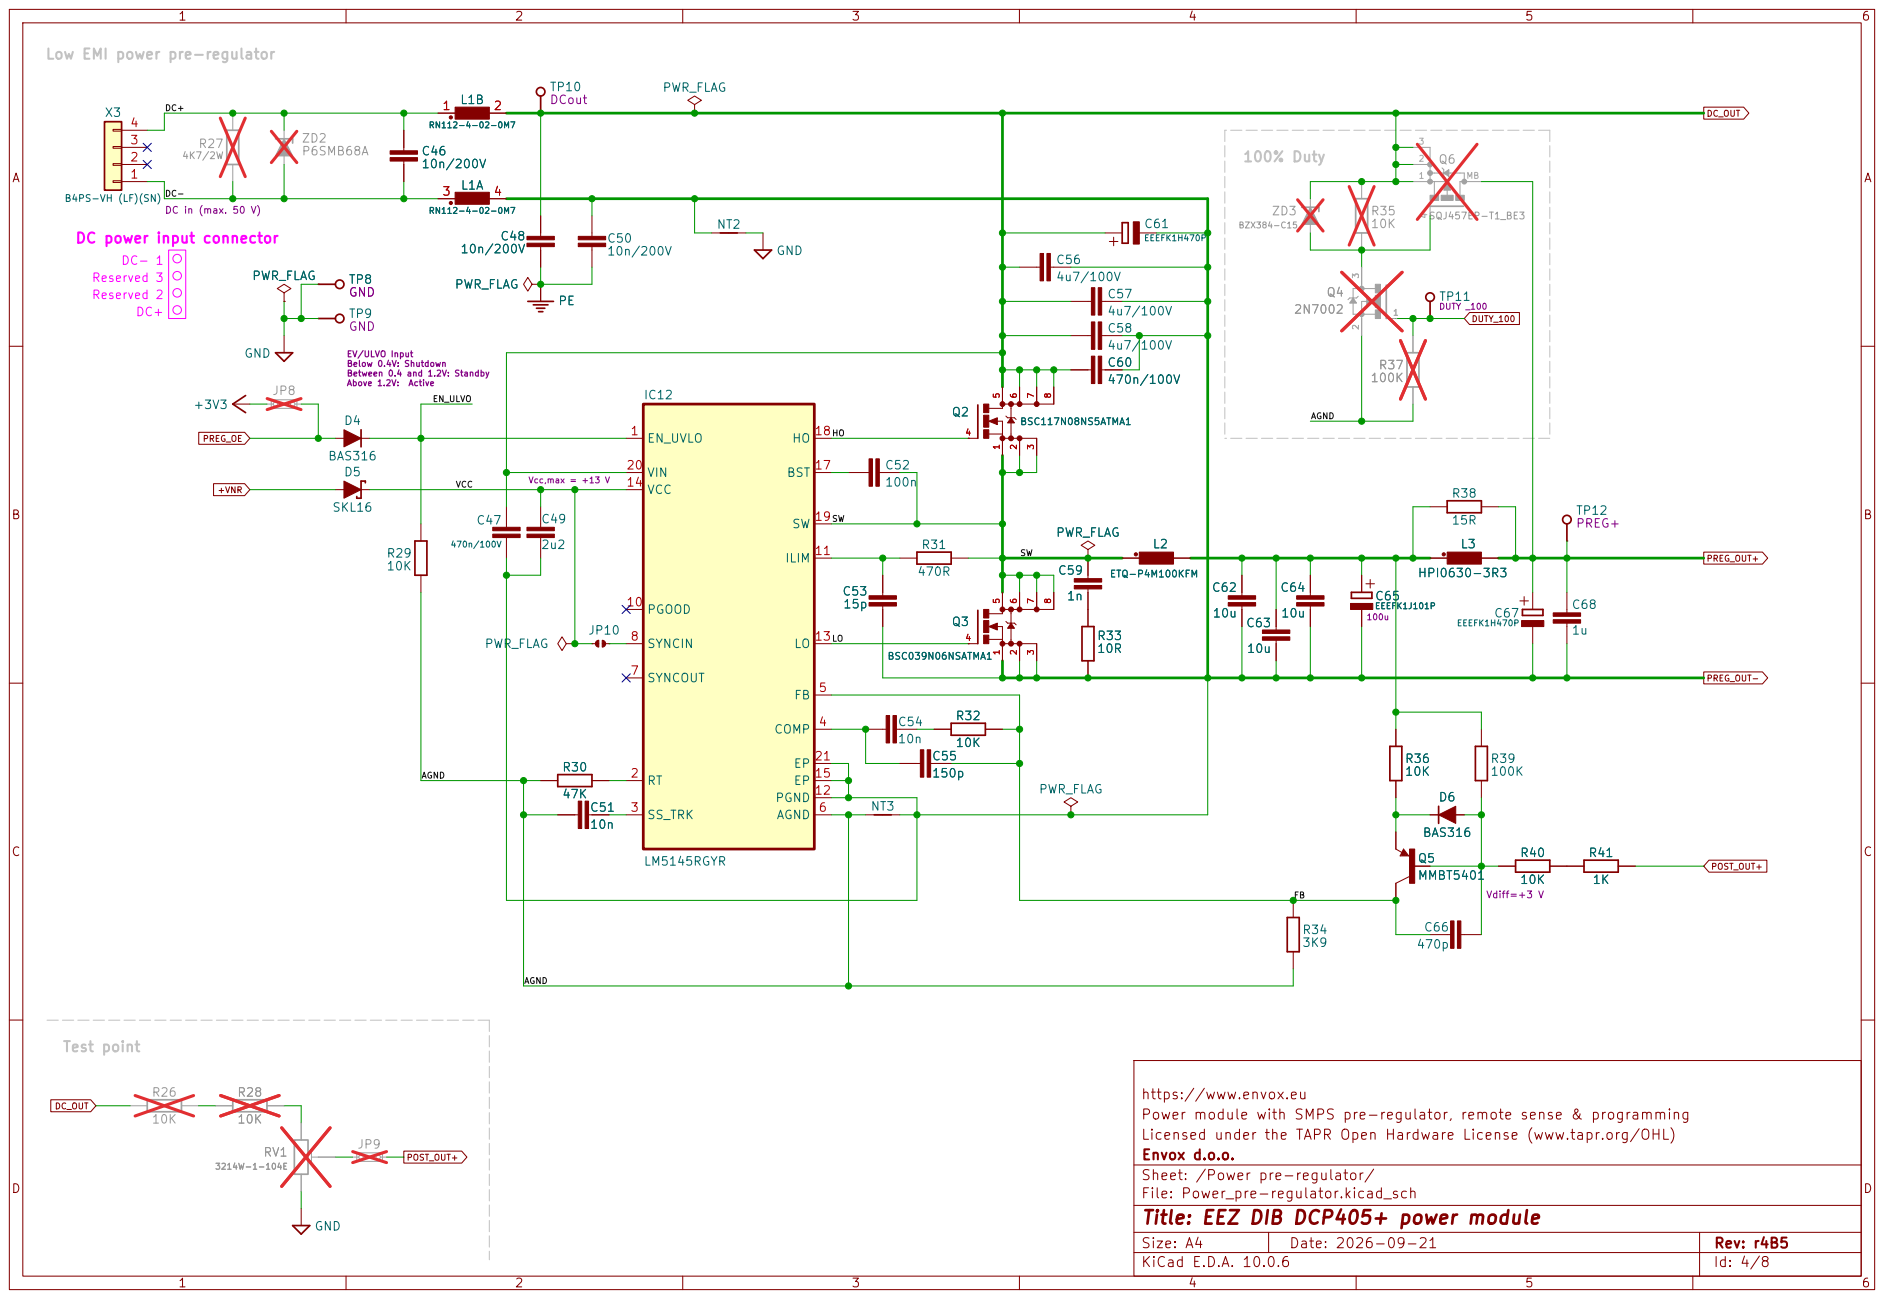
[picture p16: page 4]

Reserved 3 Low EMI power pre-regulator

Vcc,max = +13 V DC power input connector

EV/ULVO Input Below 0.4V: Shutdown Between 0.4 and 1.2V: Standby Above 1.2V: Active Reserved 2

https://www.envox.eu
Power module with SMPS pre-regulator, remote sense & programming
Licensed under the TAPR Open Hardware License (www.tapr.org/OHL)
Envox d.o.o.
Sheet: /Power pre-regulator/
File: Power_pre-regulator.kicad_sch
Title: EEZ DIB DCP405+ power module

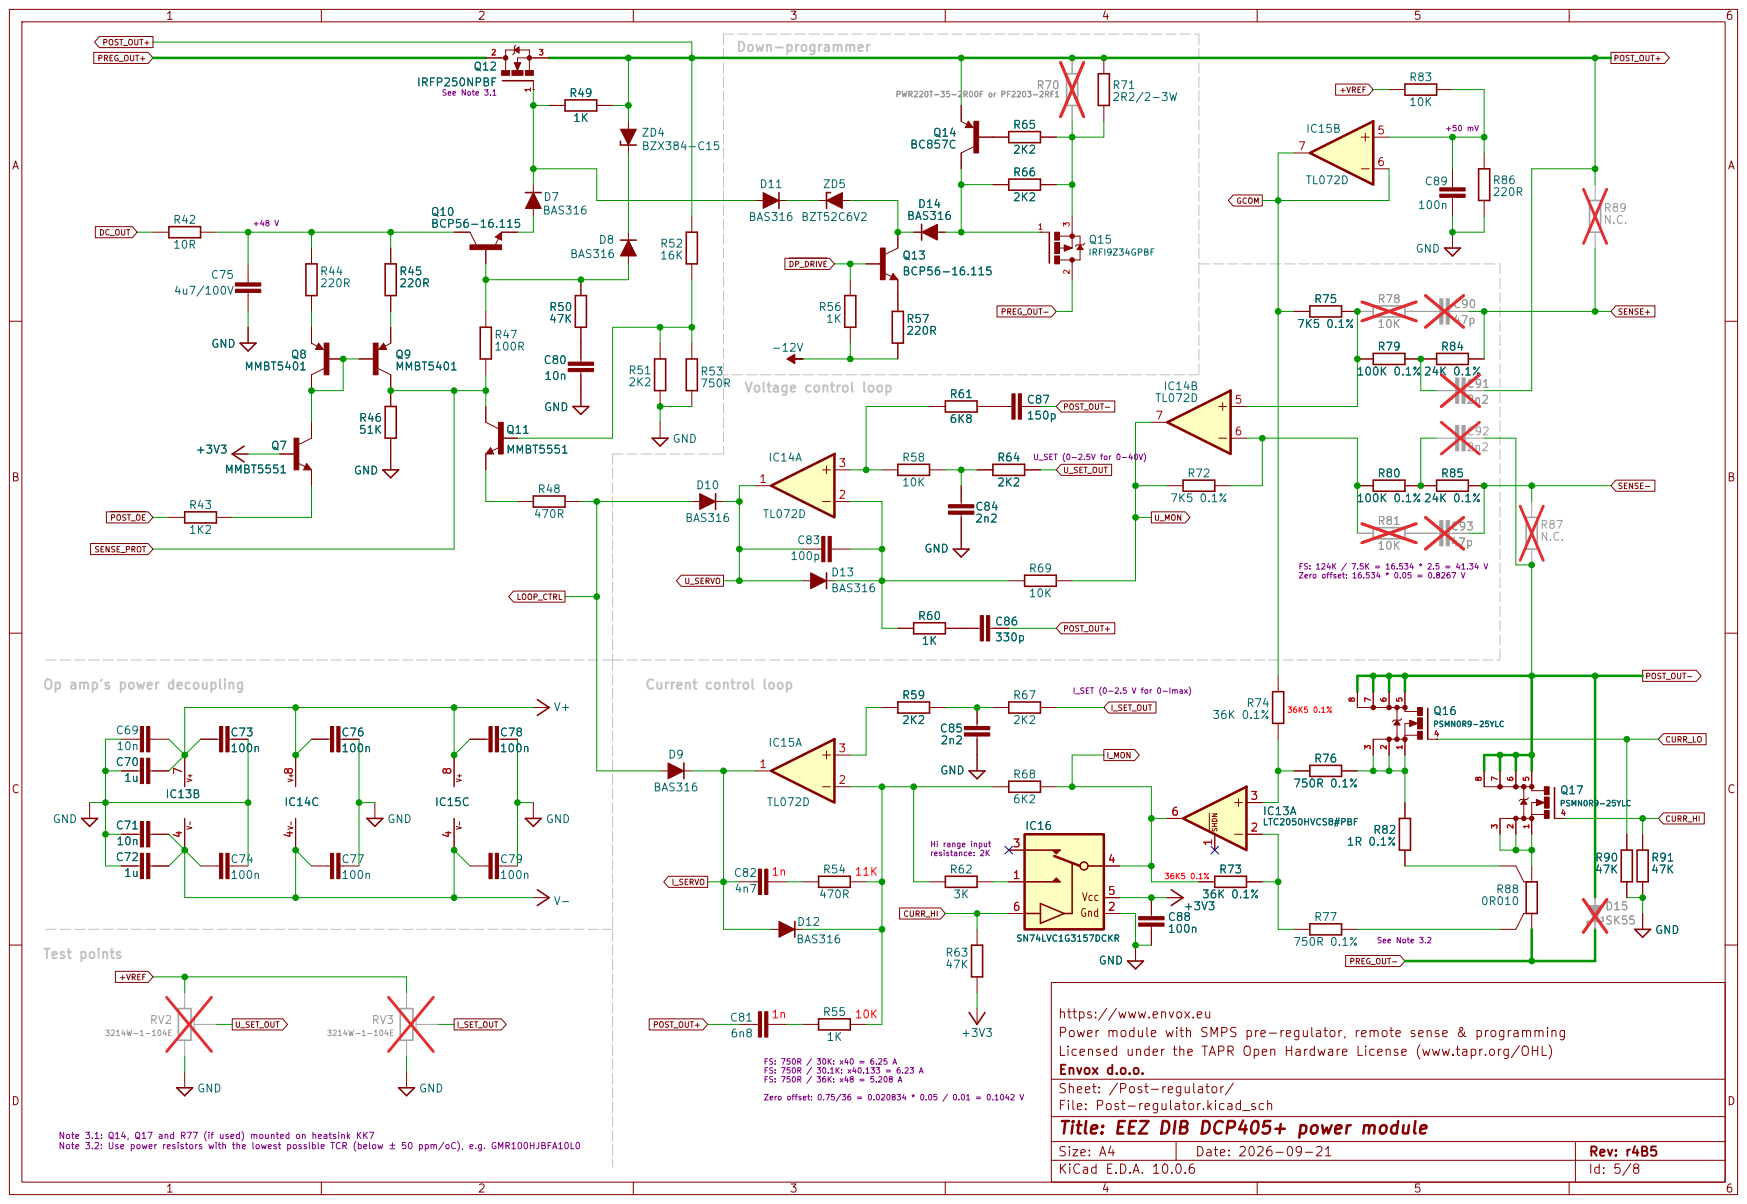
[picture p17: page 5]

Hi range input resistance: 2K Voltage control loop

Note 3.1: Q14, Q17 and R77 (if used) mounted on heatsink KK7 Note 3.2: Use power resistors with the lowest possible TCR (below ± 50 ppm/oC), e.g. GMR100HJBFA10L0 Op amp's power decoupling

See Note 3.2 Current control loop

https://www.envox.eu
Power module with SMPS pre-regulator, remote sense & programming
Licensed under the TAPR Open Hardware License (www.tapr.org/OHL)
Envox d.o.o.
Sheet: /Post-regulator/
File: Post-regulator.kicad_sch
Title: EEZ DIB DCP405+ power module

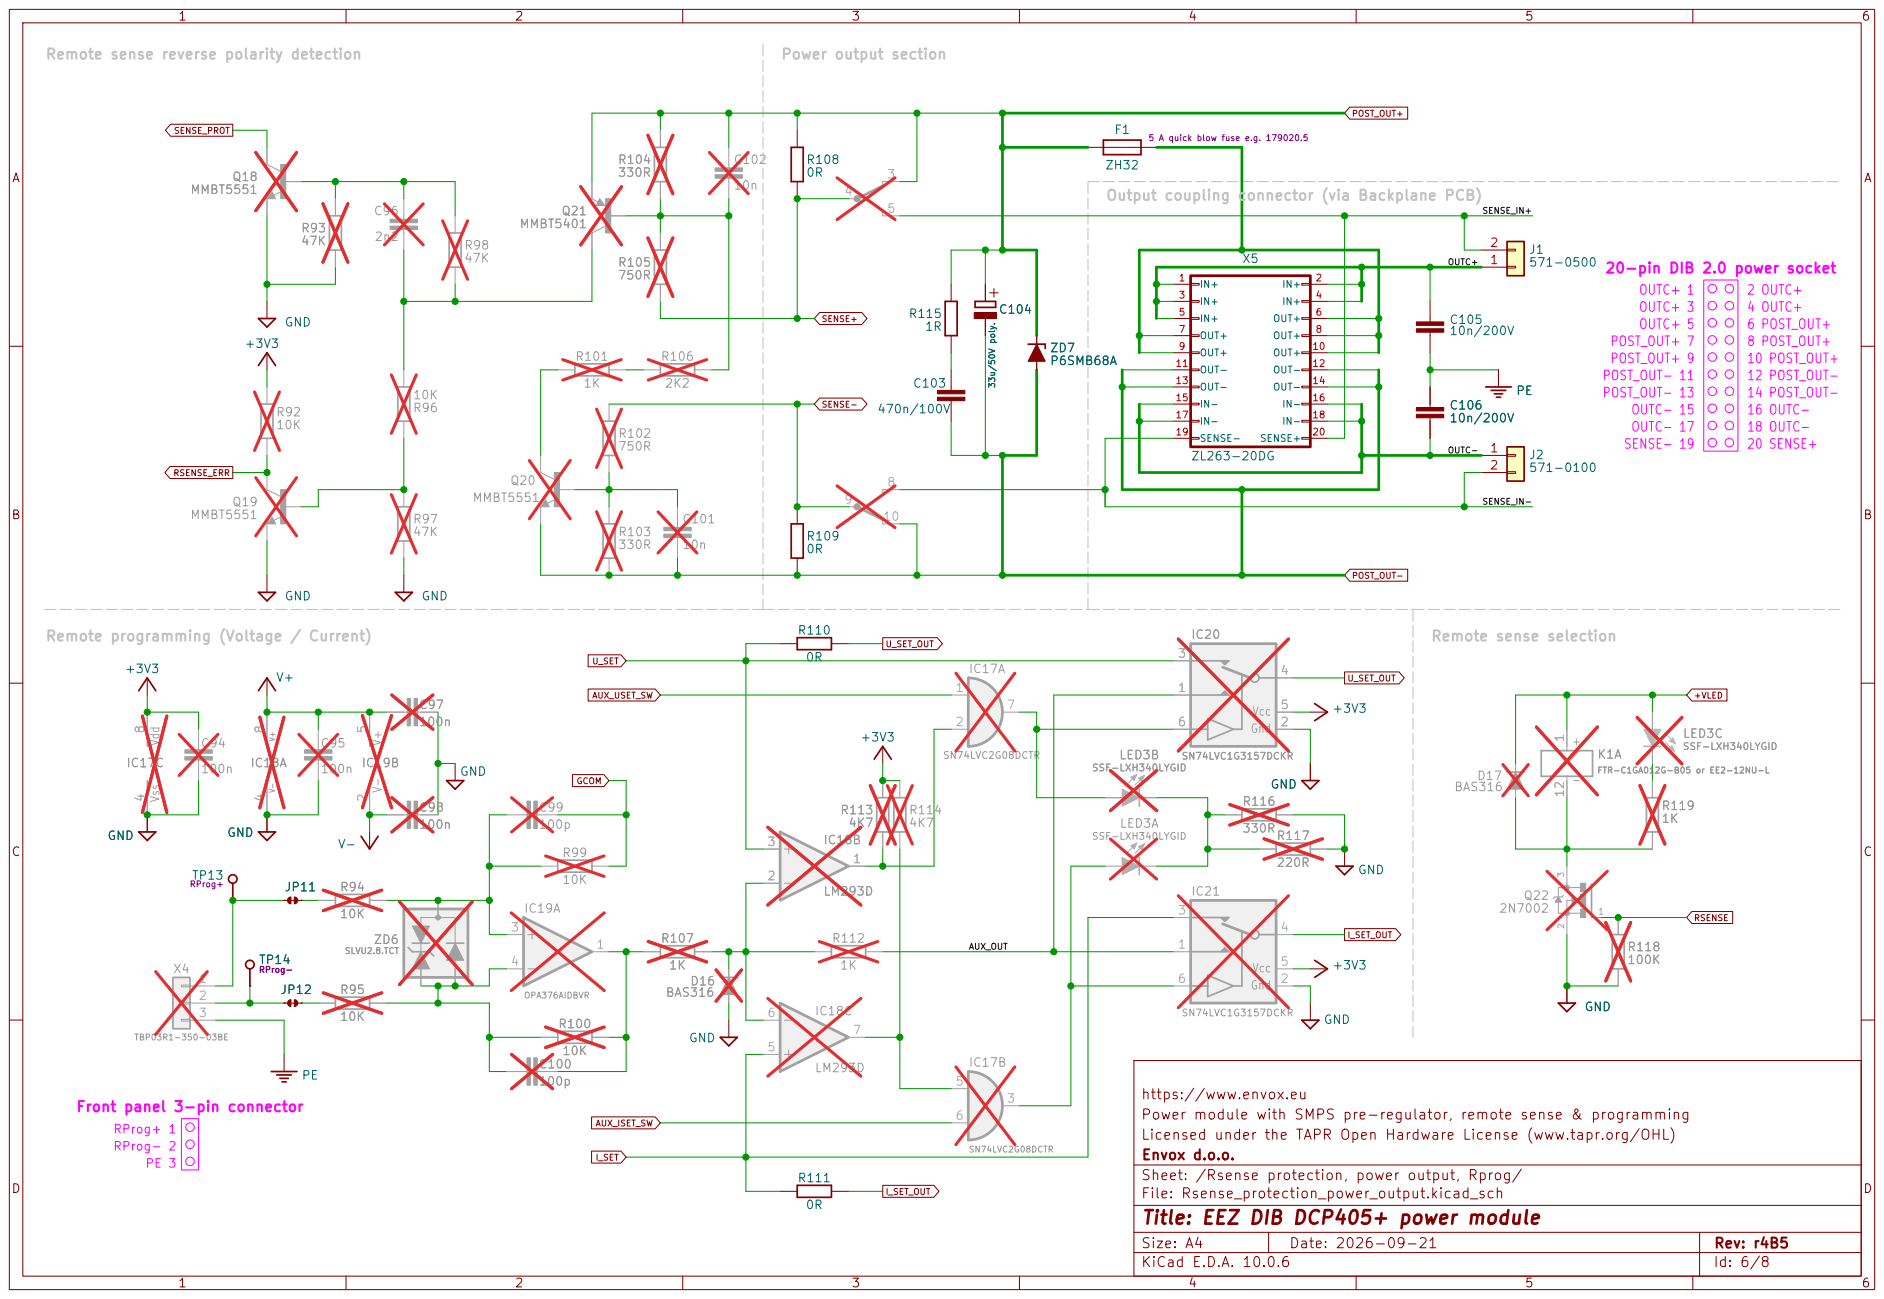
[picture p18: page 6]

Remote sense reverse polarity detection

20 SENSE+ Power output section

20-pin DIB 2.0 power socket 6 POST_OUT+

OUTC- 15 POST_OUT- 11 OUTC- 17 POST_OUT- 13 POST_OUT+ 9 OUTC+ 5 Front panel 3-pin connector

https://www.envox.eu
Power module with SMPS pre-regulator, remote sense & programming
Licensed under the TAPR Open Hardware License (www.tapr.org/OHL)
Envox d.o.o.
Sheet: /Rsense protection, power output, Rprog/
File: Rsense_protection_power_output.kicad_sch
Title: EEZ DIB DCP405+ power module

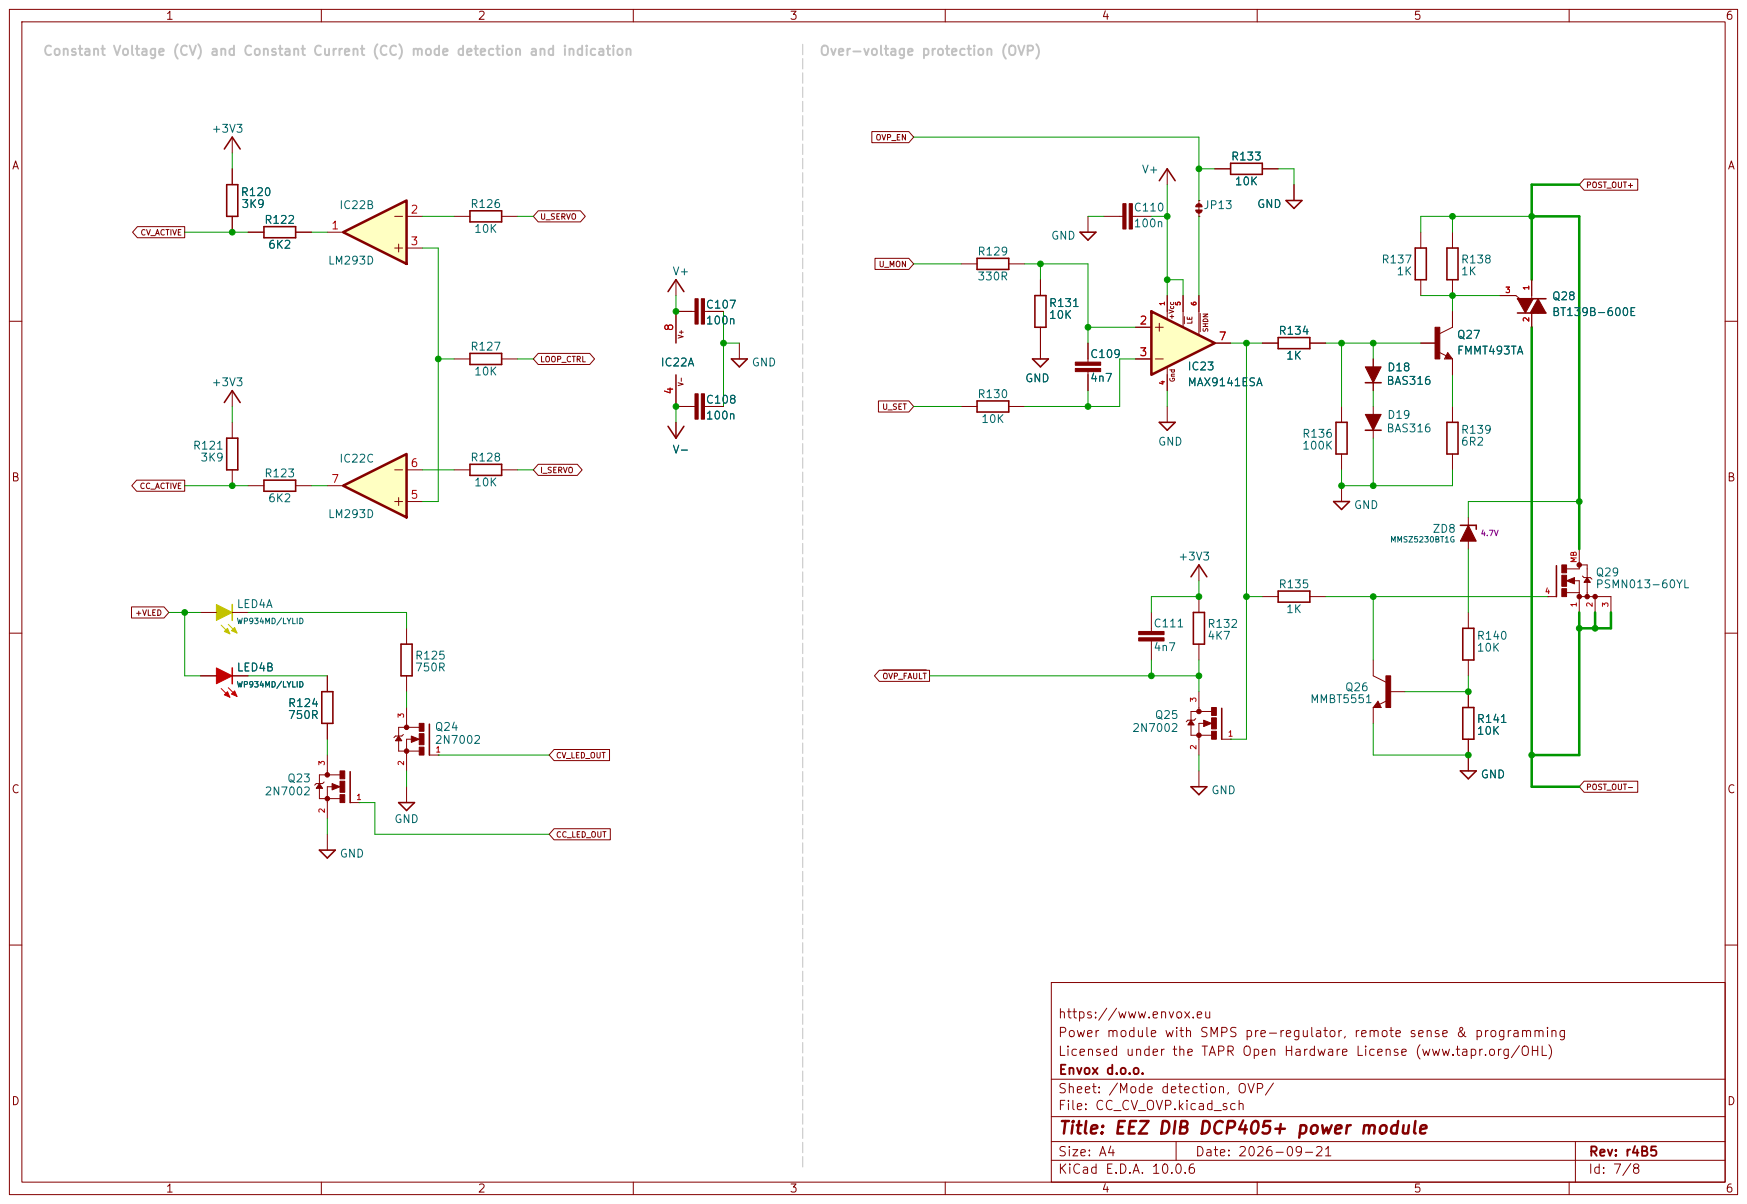
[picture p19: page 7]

https://www.envox.eu
Power module with SMPS pre-regulator, remote sense & programming
Licensed under the TAPR Open Hardware License (www.tapr.org/OHL)
Envox d.o.o.
Sheet: /Mode detection, OVP/
File: CC_CV_OVP.kicad_sch
Title: EEZ DIB DCP405+ power module

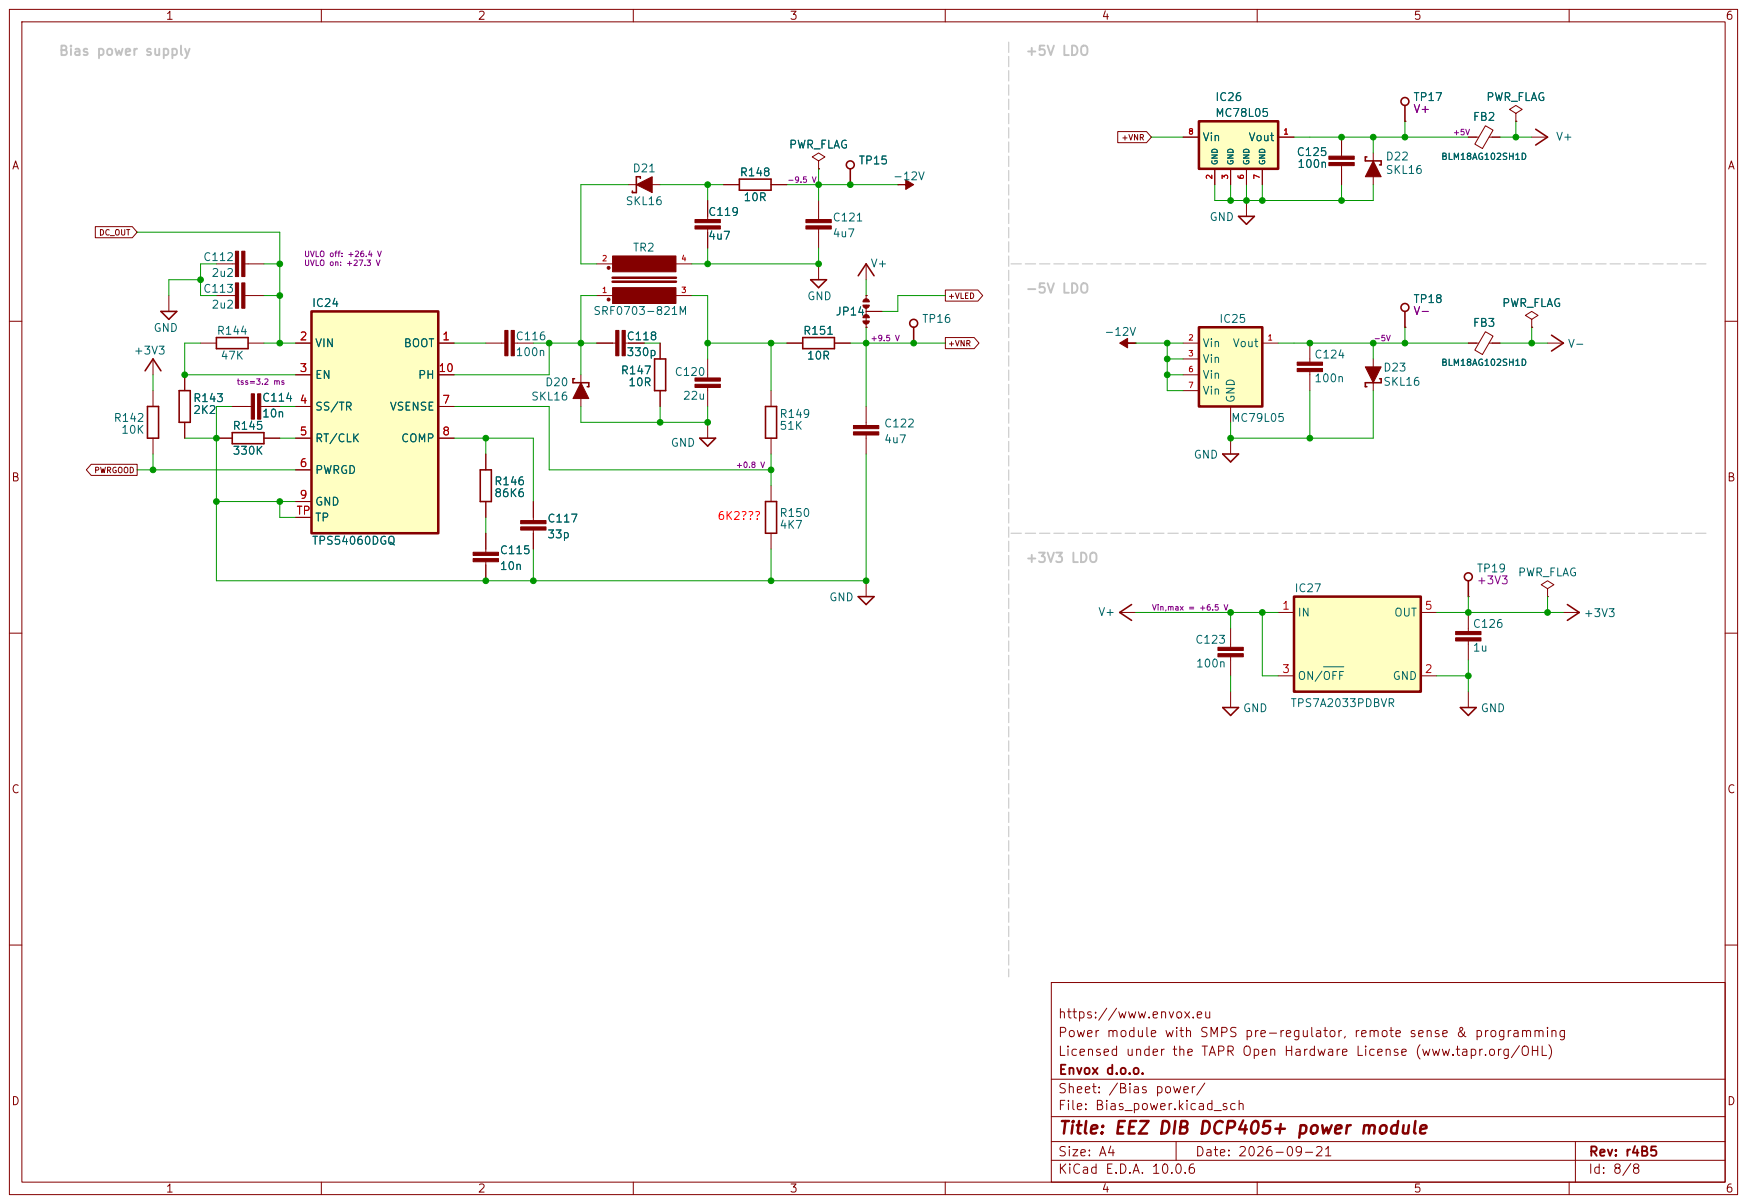
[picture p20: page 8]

Power module with SMPS pre-regulator, remote sense & programming
Licensed under the TAPR Open Hardware License (www.tapr.org/OHL)
Envox d.o.o.
Sheet: /Bias power/
File: Bias_power.kicad_sch
Title: EEZ DIB DCP405+ power module

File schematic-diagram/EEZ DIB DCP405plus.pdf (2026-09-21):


File: Rsense_protection_power_output.kicad_sch DIB isolators, EEPROM, ADC, MCU

DAC, OE, Vref, IOEXP, Temp

Bias power File: Bias_power.kicad_sch Power pre-regulator File: Power_pre-regulator.kicad_sch

Post-regulator File: Post-regulator.kicad_sch

File: DAC_Vref_IOEXP_Temp.kicad_sch Rsense protection, power output, Rprog

https://www.envox.eu
Power module with SMPS pre-regulator, remote sense & programming
Licensed under the TAPR Open Hardware License (www.tapr.org/OHL)
Envox d.o.o.
Sheet: /
File: EEZ DIB DCP405plus.kicad_sch
Title: EEZ DIB DCP405+ power module

Alternative: Mean Well LOP-200-48 HR000120

Size: A4 | Rev: r4B5
KiCad E.D.A. 10.0.6 | Id: 1/8

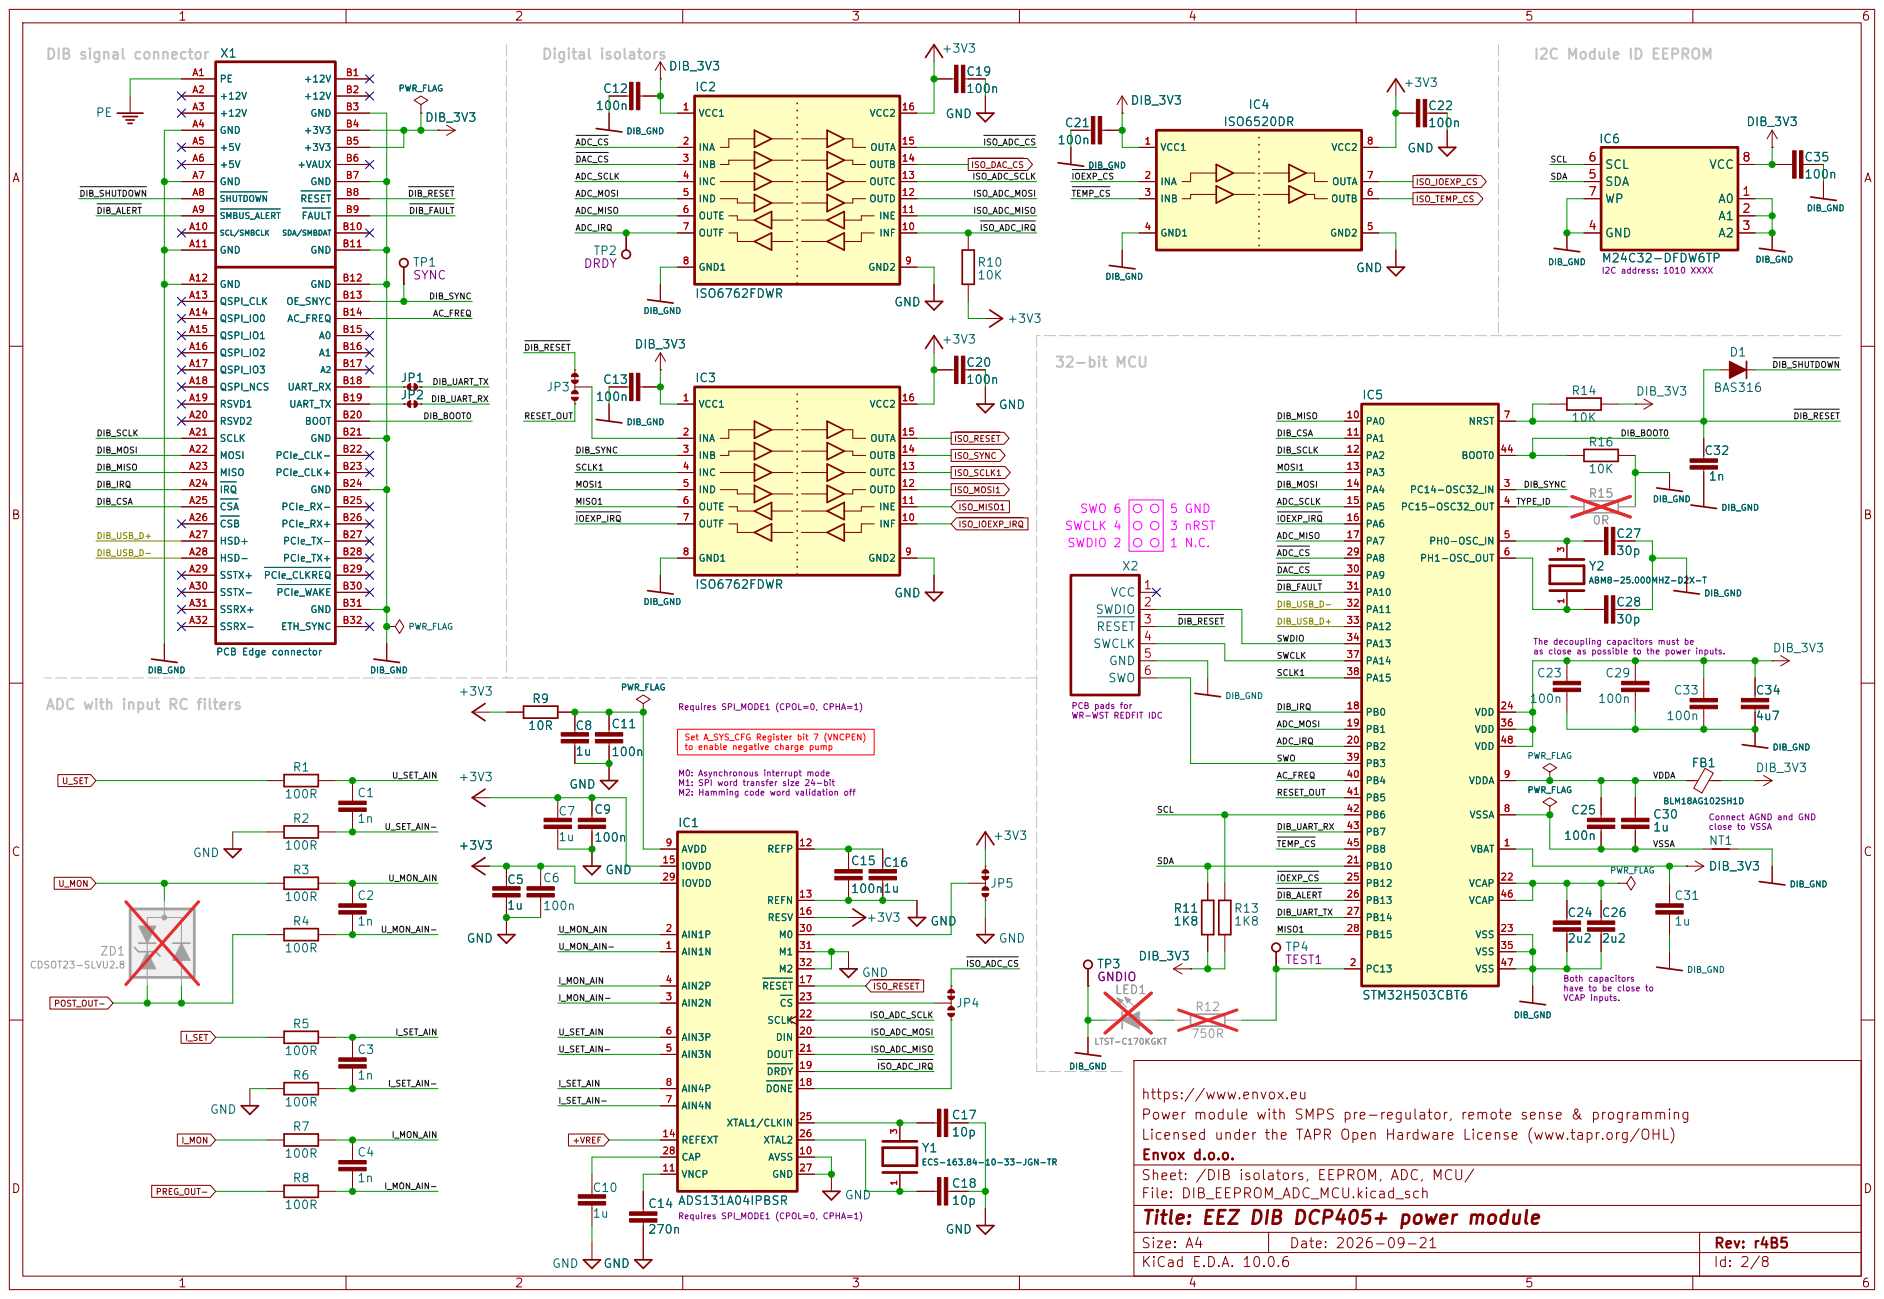
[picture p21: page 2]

PCB Edge connector PE

I2C address: 1010 XXXX PCB pads for WR-WST REDFIT IDC

SWCLK 4
close to VSSA SWDIO 2

Requires SPI_MODE1 (CPOL=0, CPHA=1) M0: Asynchronous interrupt mode M1: SPI word transfer size 24-bit M2: Hamming code word validation off ADC with input RC filters

Set A_SYS_CFG Register bit 7 (VNCPEN)
DIB_GND GND +3V3

ECS-163.84-10-33-JGN-TR JP4 GND +3V3 C15

Both capacitors have to be close to

https://www.envox.eu
Power module with SMPS pre-regulator, remote sense & programming
Licensed under the TAPR Open Hardware License (www.tapr.org/OHL)
Envox d.o.o.
Sheet: /DIB isolators, EEPROM, ADC, MCU/
File: DIB_EEPROM_ADC_MCU.kicad_sch
Title: EEZ DIB DCP405+ power module

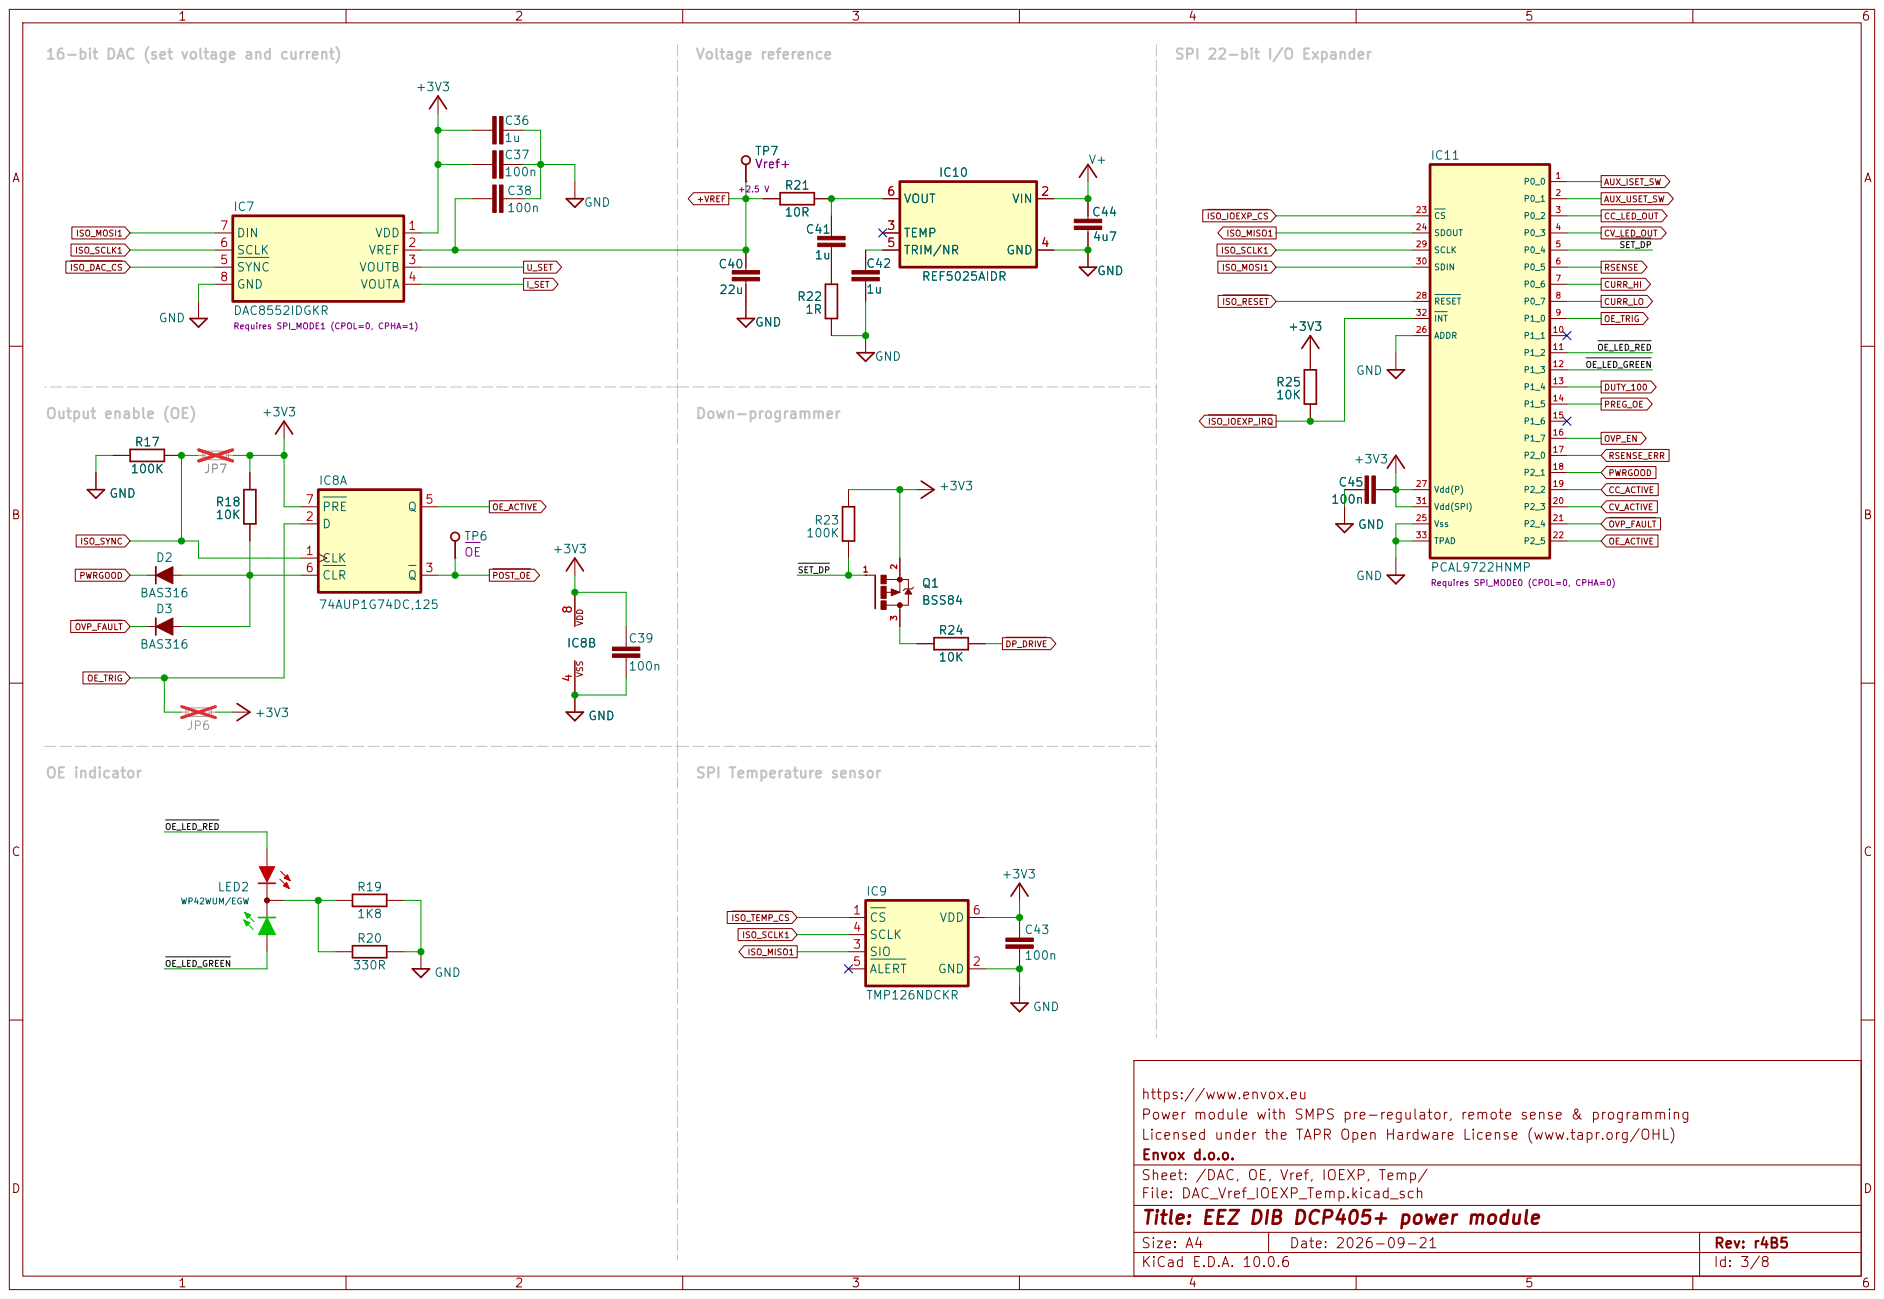
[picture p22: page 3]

Requires SPI_MODE1 (CPOL=0, CPHA=1) OE indicator

https://www.envox.eu
Power module with SMPS pre-regulator, remote sense & programming
Licensed under the TAPR Open Hardware License (www.tapr.org/OHL)
Envox d.o.o.
Sheet: /DAC, OE, Vref, IOEXP, Temp/
File: DAC_Vref_IOEXP_Temp.kicad_sch
Title: EEZ DIB DCP405+ power module

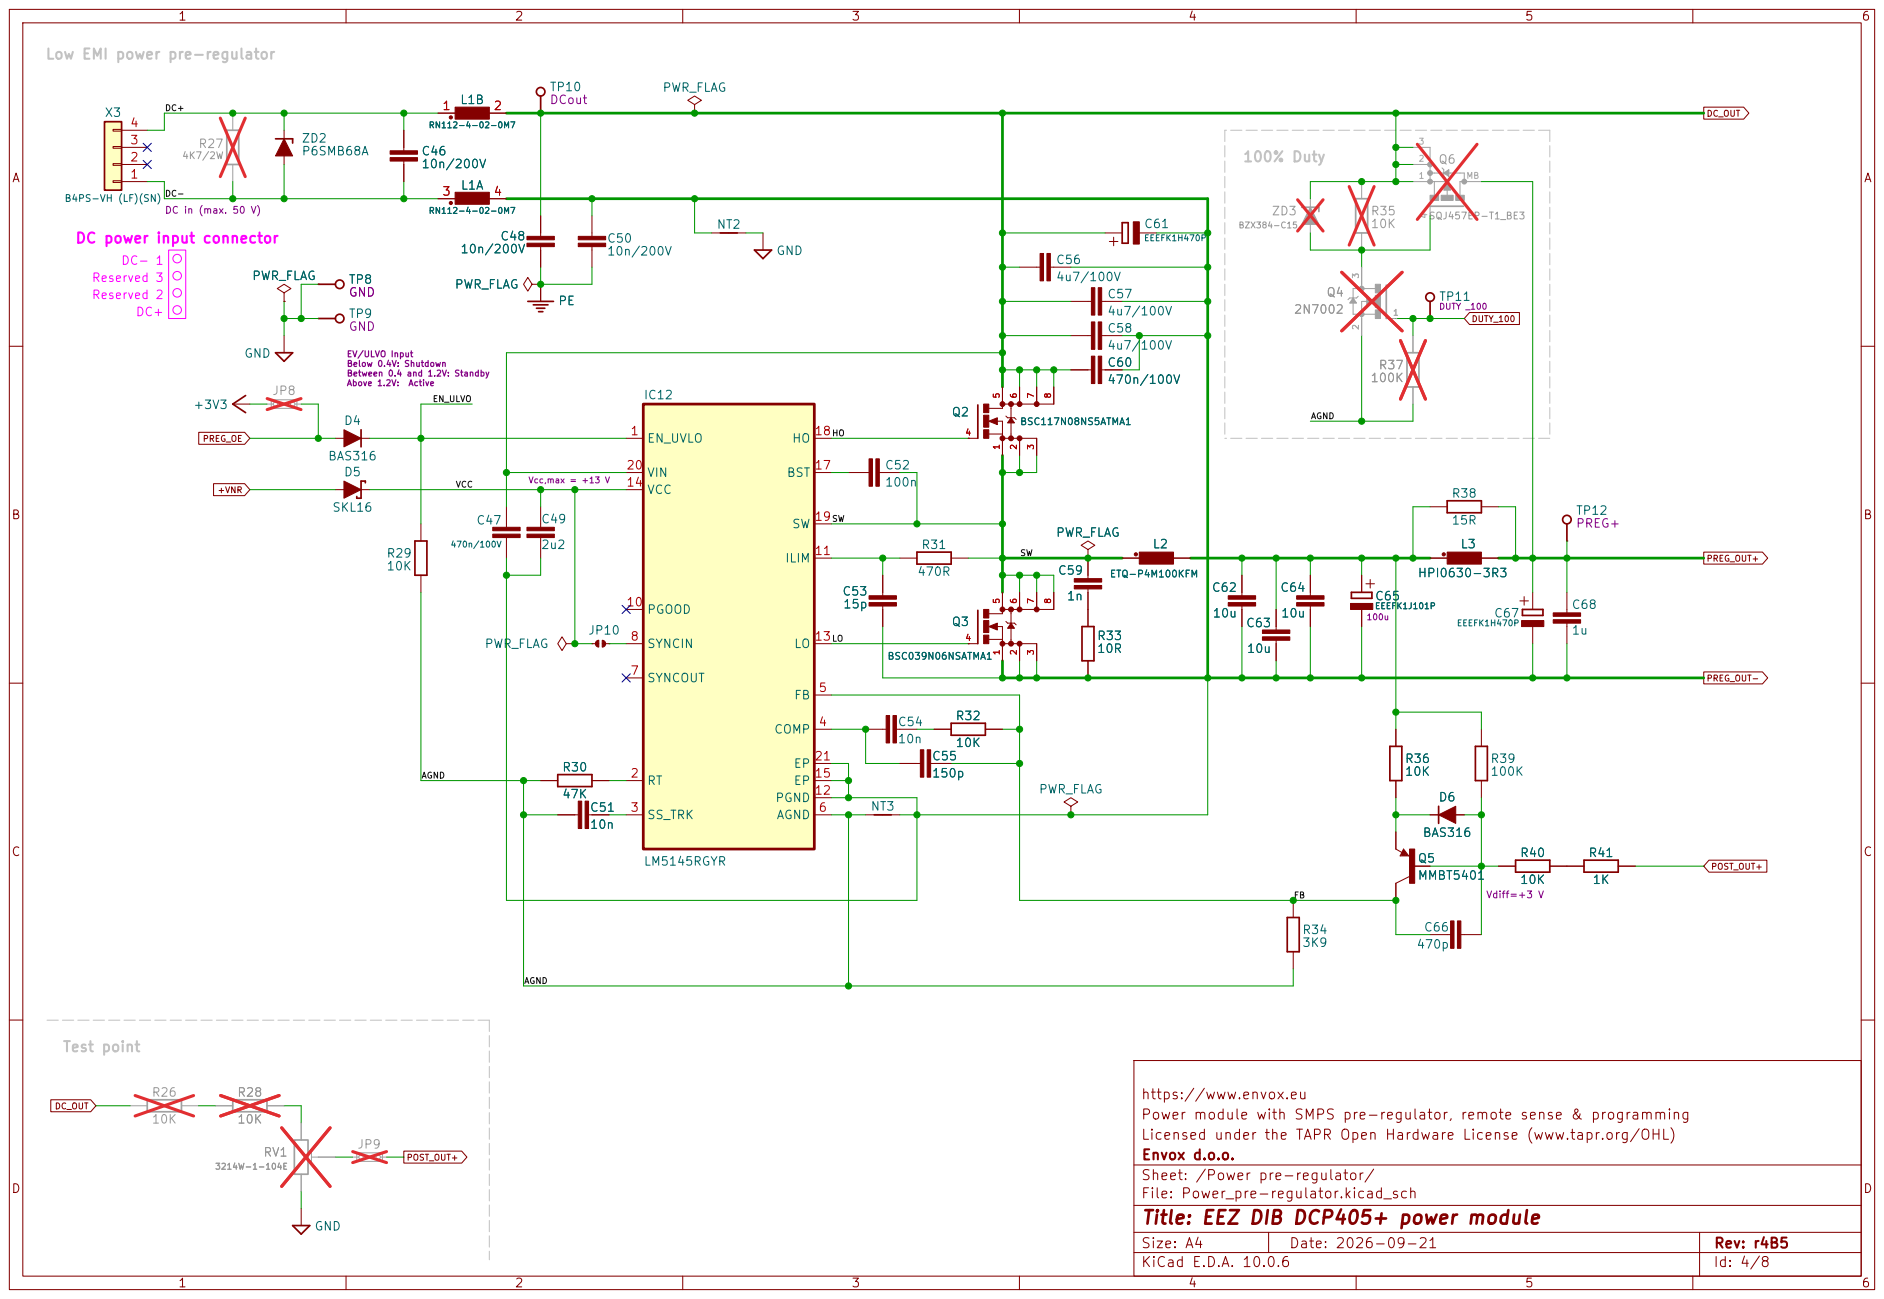
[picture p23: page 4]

Reserved 3 Low EMI power pre-regulator

Vcc,max = +13 V DC power input connector

EV/ULVO Input Below 0.4V: Shutdown Between 0.4 and 1.2V: Standby Above 1.2V: Active Reserved 2

https://www.envox.eu
Power module with SMPS pre-regulator, remote sense & programming
Licensed under the TAPR Open Hardware License (www.tapr.org/OHL)
Envox d.o.o.
Sheet: /Power pre-regulator/
File: Power_pre-regulator.kicad_sch
Title: EEZ DIB DCP405+ power module

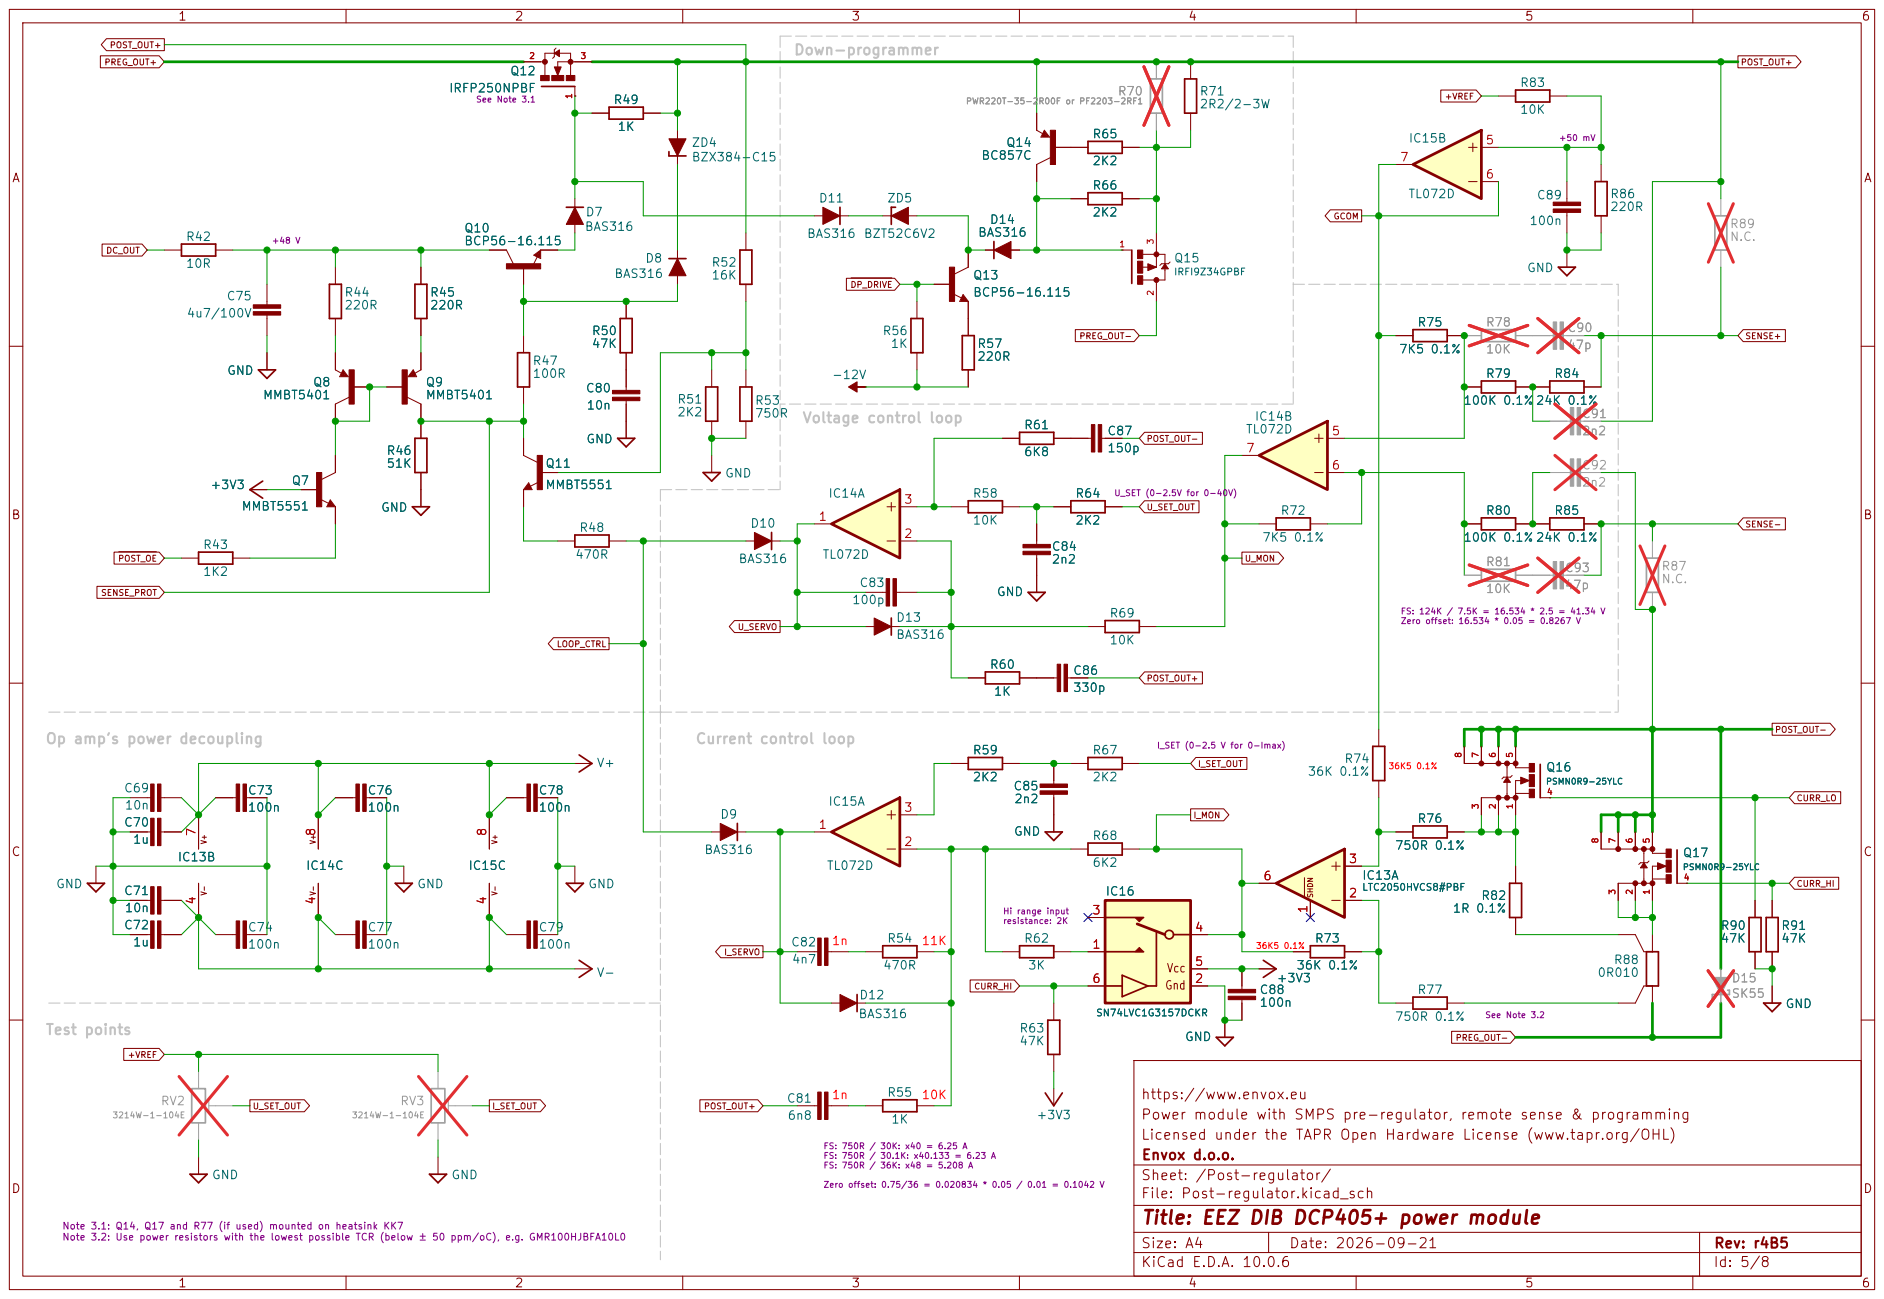
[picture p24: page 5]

Op amp's power decoupling
I_SET (0-2.5 V for 0-Imax) 1n Test points

Hi range input resistance: 2K

https://www.envox.eu
Power module with SMPS pre-regulator, remote sense & programming
Licensed under the TAPR Open Hardware License (www.tapr.org/OHL)
Envox d.o.o.
Sheet: /Post-regulator/
File: Post-regulator.kicad_sch
Title: EEZ DIB DCP405+ power module

Note 3.1: Q14, Q17 and R77 (if used) mounted on heatsink KK7 Note 3.2: Use power resistors with the lowest possible TCR (below ± 50 ppm/oC), e.g. GMR100HJBFA10L0


Remote sense reverse polarity detection

20 SENSE+ Power output section

20-pin DIB 2.0 power socket 6 POST_OUT+

OUTC- 15 POST_OUT- 11 OUTC- 17 POST_OUT- 13 POST_OUT+ 9 OUTC+ 5 Front panel 3-pin connector

https://www.envox.eu
Power module with SMPS pre-regulator, remote sense & programming
Licensed under the TAPR Open Hardware License (www.tapr.org/OHL)
Envox d.o.o.
Sheet: /Rsense protection, power output, Rprog/
File: Rsense_protection_power_output.kicad_sch
Title: EEZ DIB DCP405+ power module


https://www.envox.eu
Power module with SMPS pre-regulator, remote sense & programming
Licensed under the TAPR Open Hardware License (www.tapr.org/OHL)
Envox d.o.o.
Sheet: /Mode detection, OVP/
File: CC_CV_OVP.kicad_sch
Title: EEZ DIB DCP405+ power module


Power module with SMPS pre-regulator, remote sense & programming
Licensed under the TAPR Open Hardware License (www.tapr.org/OHL)
Envox d.o.o.
Sheet: /Bias power/
File: Bias_power.kicad_sch
Title: EEZ DIB DCP405+ power module

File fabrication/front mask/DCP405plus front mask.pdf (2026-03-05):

# DCP405+

Power; Sense; +2.5V full scale

RPC RPV Sense

Green: Acve
Red: Coupled

DC Power Source


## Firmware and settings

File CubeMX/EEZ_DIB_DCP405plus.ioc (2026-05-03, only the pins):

Mcu.UserName=STM32H503CBTx
PA0.GPIO_Label=DIB_MISO
PA0.Signal=SPI1_MISO
PA1.GPIO_Label=DIB_CSA
PA1.Signal=SPI1_NSS
PA10.GPIO_Label=DIB_FAULT
PA10.Signal=GPIO_Output
PA11.Signal=USB_DM
PA12.Signal=USB_DP
PA13(JTMS/SWDIO).GPIO_Label=JTAG_DIO
PA13(JTMS/SWDIO).Signal=DEBUG_JTMS-SWDIO
PA14(JTCK/SWCLK).GPIO_Label=JTAG_CLK
PA14(JTCK/SWCLK).Signal=DEBUG_JTCK-SWCLK
PA15(JTDI).GPIO_Label=SCLK1
PA15(JTDI).Signal=SPI3_SCK
PA2.GPIO_Label=DIB_CLK
PA2.Signal=SPI1_SCK
PA3.GPIO_Label=MOSI1
PA3.Signal=SPI3_MOSI
PA4.GPIO_Label=DIB_MOSI
PA4.Signal=SPI1_MOSI
PA5.GPIO_Label=ADC_SCLK
PA5.Signal=SPI2_SCK
PA6.GPIO_Label=IOEXP_IRQ
PA6.Signal=GPXTI6
PA7.GPIO_Label=ADC_MISO
PA7.Signal=SPI2_MISO
PA8.GPIO_Label=ADC_CS
PA8.Signal=GPIO_Output
PA9.GPIO_Label=DAC_CS
PA9.Signal=GPIO_Output
PB0.GPIO_Label=DIB_IRQ
PB0.Signal=GPIO_Output
PB1.GPIO_Label=ADC_MOSI
PB1.Signal=SPI2_MOSI
PB10.GPIO_Label=DIB_SDA
PB10.Signal=I2C1_SDA
PB12.GPIO_Label=IOEXP_CS
PB12.Signal=GPIO_Output
PB13.GPIO_Label=DIB_ALERT
PB13.Signal=I2C1_SMBA
PB14.Signal=USART1_TX
PB15.GPIO_Label=MISO1
PB15.Signal=SPI3_MISO
PB2.GPIO_Label=ADC_IRQ
PB2.Signal=GPIO_Input
PB3(JTDO/TRACESWO).GPIO_Label=JTAG_SWO
PB3(JTDO/TRACESWO).Signal=DEBUG_JTDO-SWO
PB4(NJTRST).GPIO_Label=AC_FREQ
PB4(NJTRST).Signal=S_TIM1_CH2
PB6.GPIO_Label=DIB_SCL
PB6.Signal=I2C1_SCL
PB7.Signal=USART1_RX
PB8.GPIO_Label=TEMP_CS
PB8.Signal=GPIO_Output
PC13.GPIO_Label=ACT_LED
PC13.Signal=GPIO_Output
PC15-OSC32_OUT(OSC32_OUT).GPIO_Label=TYPE_ID
PC15-OSC32_OUT(OSC32_OUT).Signal=GPIO_Input
PH0-OSC_IN(PH0).Signal=RCC_OSC_IN
PH1-OSC_OUT(PH1).Signal=RCC_OSC_OUT

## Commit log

2025-10-22 First KiCad project commit
    [Bias_power.kicad_sch, CC_CV_OVP.kicad_sch, DAC_Vref_IOEXP_Temp.kicad_sch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]
2025-10-23 Schematics info updated
    [Bias_power.kicad_sch, CC_CV_OVP.kicad_sch, DAC_Vref_IOEXP_Temp.kicad_sch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]
2025-10-23 JP symbols update
    [Bias_power.kicad_sch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]
2025-10-23 Gerbers update
    [EEZ DIB DCP405plus-B_Cu.gbr, EEZ DIB DCP405plus-B_Mask.gbr, EEZ DIB DCP405plus-B_Paste.gbr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]
2025-10-23 Front mask DXF files
    [EEZ DIB DCP405plus front mask-Edge_Cuts.dxf, EEZ DIB DCP405plus front mask.dxf]
2026-01-03 X3 type changed
    [Bias_power.kicad_sch, CC_CV_OVP.kicad_sch, DAC_Vref_IOEXP_Temp.kicad_sch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]
2026-01-06 DIB connector update
    [Bias_power.kicad_sch, CC_CV_OVP.kicad_sch, DAC_Vref_IOEXP_Temp.kicad_sch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]
2026-01-07 OSHW certification mark, front mask STEP color
    [Bias_power.kicad_sch, DAC_Vref_IOEXP_Temp.kicad_sch, DIB_EEPROM_ADC_MCU.kicad_sch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]
2026-02-17 Q18, Q19 model fixed
    [Bias_power.kicad_sch, CC_CV_OVP.kicad_sch, DAC_Vref_IOEXP_Temp.kicad_sch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]
2026-02-17 BOM update
    [EEZ DIB DCP405plus BOM.ods, EEZ DIB DCP405plus.ods]
2026-02-25 JP3 update (Reset out select)
    [Bias_power.kicad_sch, CC_CV_OVP.kicad_sch, DAC_Vref_IOEXP_Temp.kicad_sch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]
2026-03-01 #2, #3, image of the assembled module
    [Bias_power.kicad_sch, CC_CV_OVP.kicad_sch, DAC_Vref_IOEXP_Temp.kicad_sch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]
2026-03-05 Pullups for OE indicator added
    [Bias_power.kicad_sch, CC_CV_OVP.kicad_sch, DAC_Vref_IOEXP_Temp.kicad_sch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]
2026-03-05 Front mask silkscreen corrections
    [EEZ DIB DCP405plus front mask-B_Cu.gbr, EEZ DIB DCP405plus front mask-Edge_Cuts.gbr, EEZ DIB DCP405plus front mask-F_Cu.gbr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]
2026-03-13 Front mask gerbers update
    [EEZ DIB DCP405plus front mask-B_Cu.gbr, EEZ DIB DCP405plus front mask-B_Mask.gbr, EEZ DIB DCP405plus front mask-B_Paste.gbr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]
2026-03-28 Silkscreen updated
    [DIB_EEPROM_ADC_MCU.kicad_sch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]
2026-04-29 OSHWA logo added, KiCad 10 migration
    [Bias_power.kicad_sch, CC_CV_OVP.kicad_sch, DAC_Vref_IOEXP_Temp.kicad_sch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]
2026-05-10 Basic variant schematics PDF
    [Bias_power.kicad_sch, CC_CV_OVP.kicad_sch, DAC_Vref_IOEXP_Temp.kicad_sch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]
2026-05-10 BOM and Gerbers update
    [Bias_power.kicad_sch, CC_CV_OVP.kicad_sch, DAC_Vref_IOEXP_Temp.kicad_sch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]
2026-06-26 #8, schematics annotated
    [Bias_power.kicad_sch, CC_CV_OVP.kicad_sch, DAC_Vref_IOEXP_Temp.kicad_sch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]
2026-06-30 Schematics update (power socket pinout)
    [Bias_power.kicad_sch, CC_CV_OVP.kicad_sch, DAC_Vref_IOEXP_Temp.kicad_sch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]
2026-09-20 Basic front mask gerbers, two test points, BOM updated
    [Bias_power.kicad_sch, CC_CV_OVP.kicad_sch, DAC_Vref_IOEXP_Temp.kicad_sch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]
2026-09-21 ADC DRDY test point added
    [Bias_power.kicad_sch, CC_CV_OVP.kicad_sch, DAC_Vref_IOEXP_Temp.kicad_sch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]
2026-09-21 DIB_SYNC connected to PC14
    [DAC_Vref_IOEXP_Temp.kicad_sch, DIB_EEPROM_ADC_MCU.kicad_sch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]
2026-10-21 Front masks added into main schematics
2026-10-21 PCB layout update
2026-10-24 Wire harness added
2026-11-03 BOM updated
2026-11-06 Gerbers folder reorganized
2026-11-06 Wireharness BOM added
